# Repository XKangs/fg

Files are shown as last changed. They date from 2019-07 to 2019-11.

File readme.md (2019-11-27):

#block dirgram
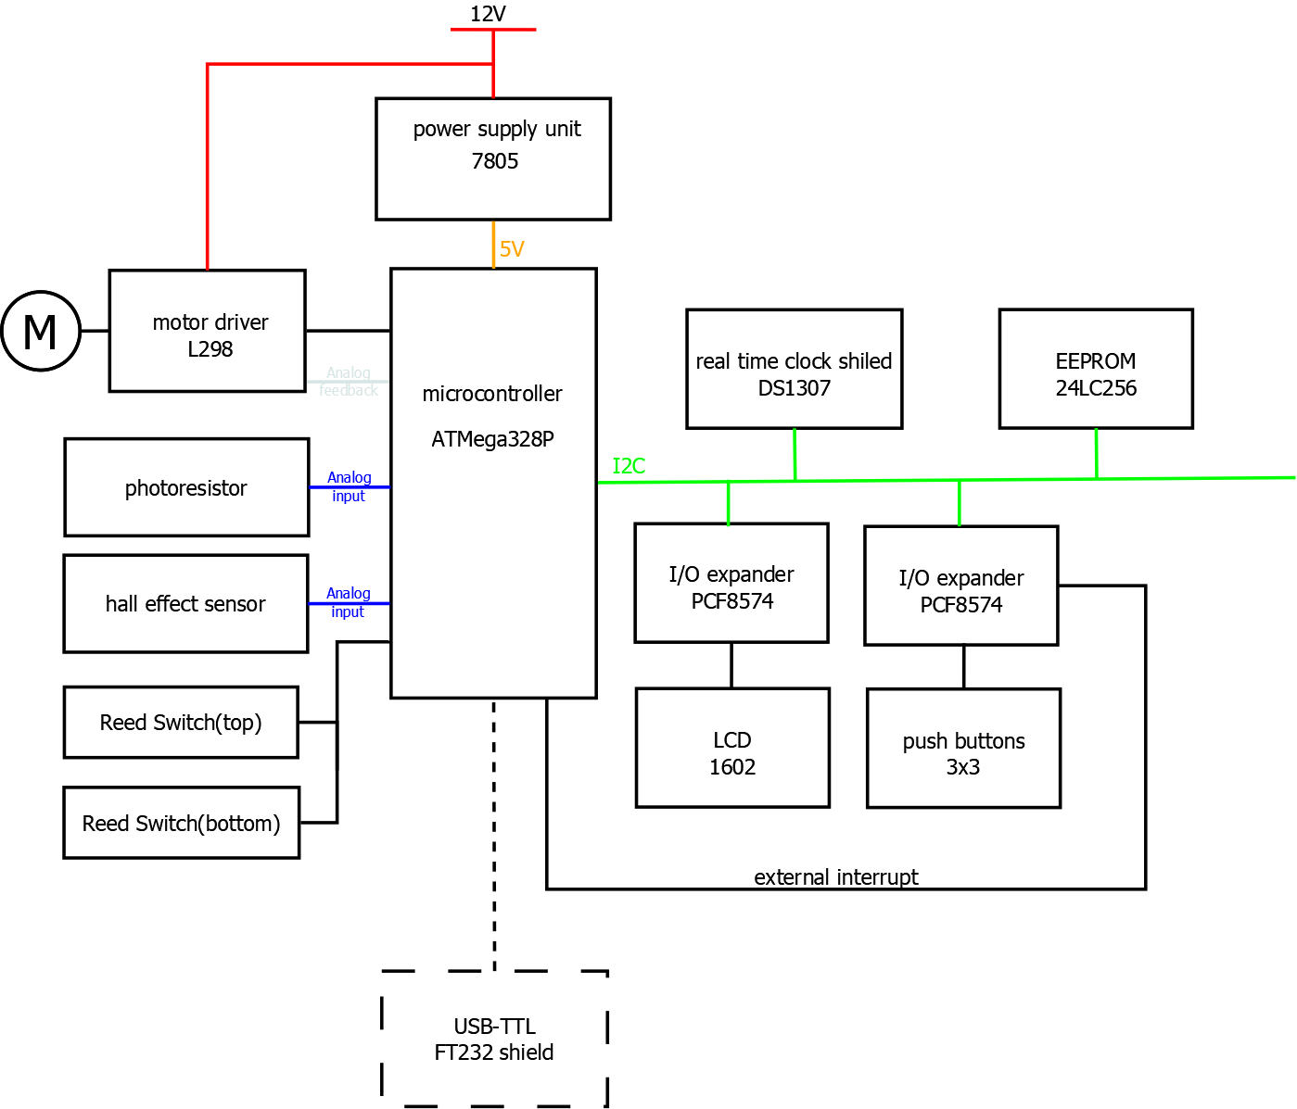
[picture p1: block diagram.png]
block diagram


---
this branch is for writting my report, it has its own schematic and PCB layout but doesn't have the code because it haven't been manufactured and built. 

hopefully somebody can finish it one day, I have spent soooooo much time on it...

---
xKang 
27 November 2019

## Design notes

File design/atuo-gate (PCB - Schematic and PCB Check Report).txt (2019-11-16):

Schematic and PCB Check Report
------------------------------

Report Written:     Saturday, November 16, 2019
Project Path:       C:\Users\xKang\Desktop\fg\design\atuo-gate.prj
Design Path:        C:\Users\xKang\Desktop\fg\design\atuo-gate.pcb
Design Title:       
Created:            27/07/2019 12:11:12 AM
Last Saved:         14/11/2019 2:04:38 PM
Editing Time:       1642 min
Units:              thou (precision 0)

Checking integrity of Schematic "C:\Users\xKang\Desktop\fg\design\atuo-gate.prj" with PCB "C:\Users\xKang\Desktop\fg\design\atuo-gate.pcb"
==========================================================================================================================================

End Of Report.

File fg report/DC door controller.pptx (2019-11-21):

## DC door controller

By Kevin

## Block diagram

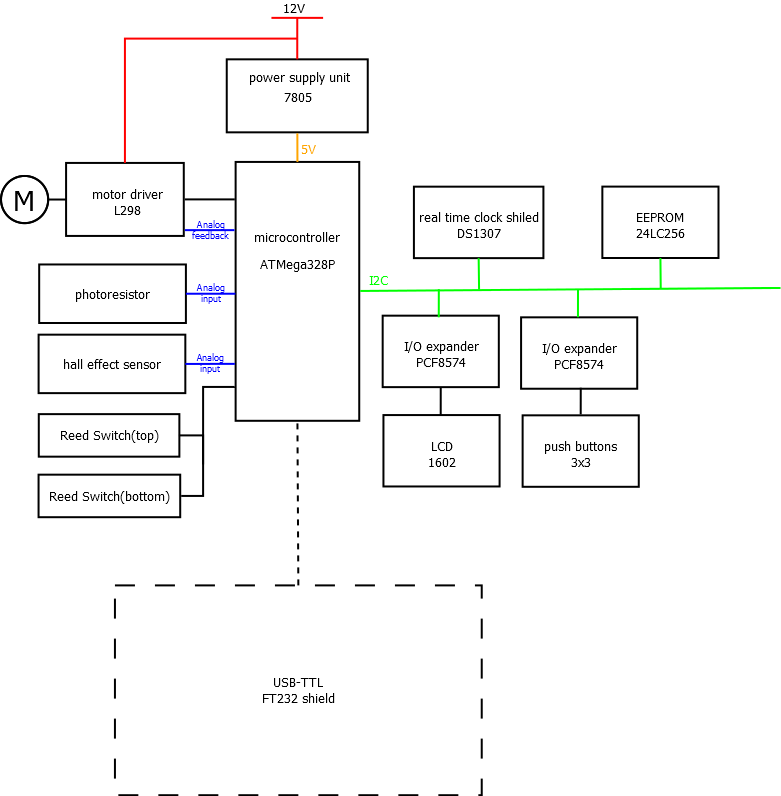
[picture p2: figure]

## components

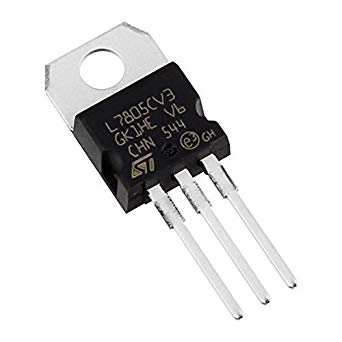
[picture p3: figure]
Image result for lm7805

PSU LM7805

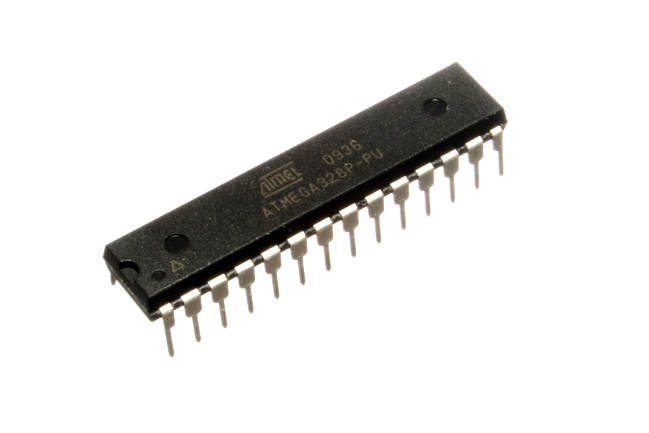
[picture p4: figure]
Image result for an At mega 328P

Microcontroller At mega 328P

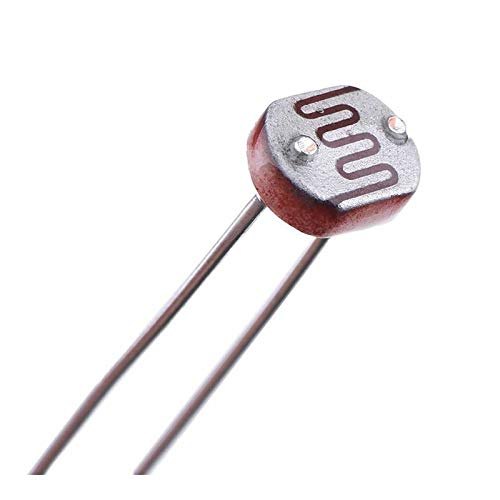
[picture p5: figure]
Image result for Photoresistor

Photoresistor

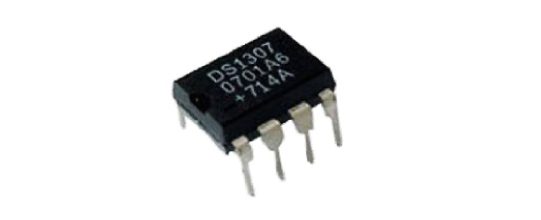
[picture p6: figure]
Image result for DS1307 ic

RTC DS1307

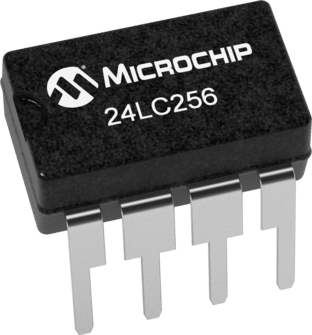
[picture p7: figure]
Image result for 24LC256

EEPROM 24LC256

## components

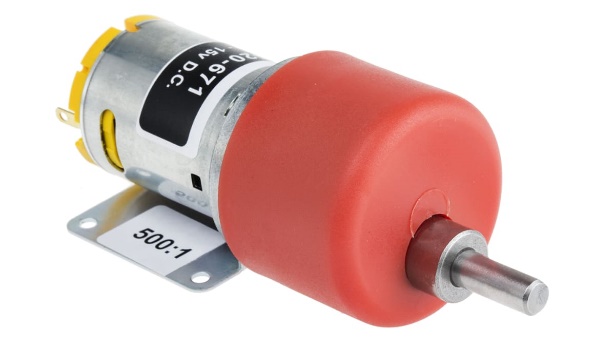
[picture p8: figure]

DC Motor with 500:1 gearbox

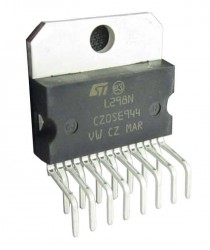
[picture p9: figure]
Image result for L298N

Motor drive
L298N

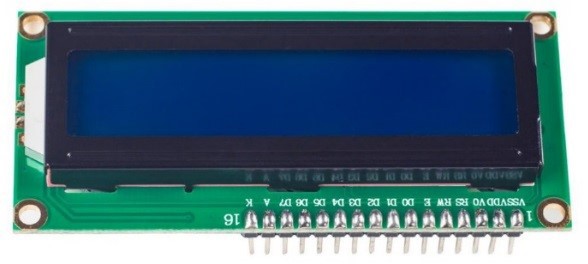
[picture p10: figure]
Image result for lcd 1602

1602 LCD

## PCB

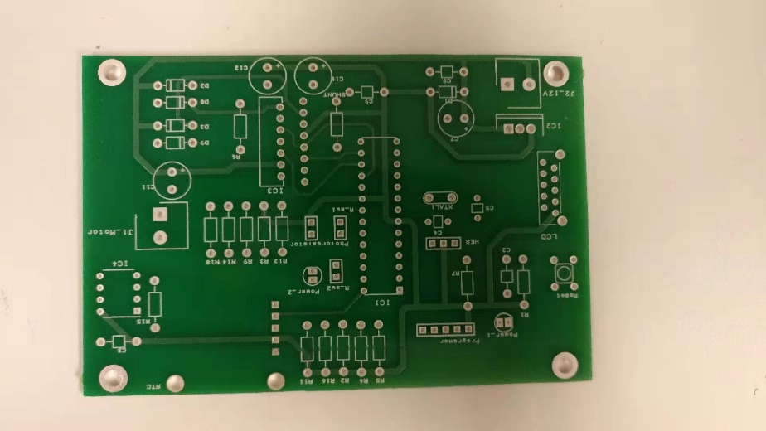
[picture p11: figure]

## interior

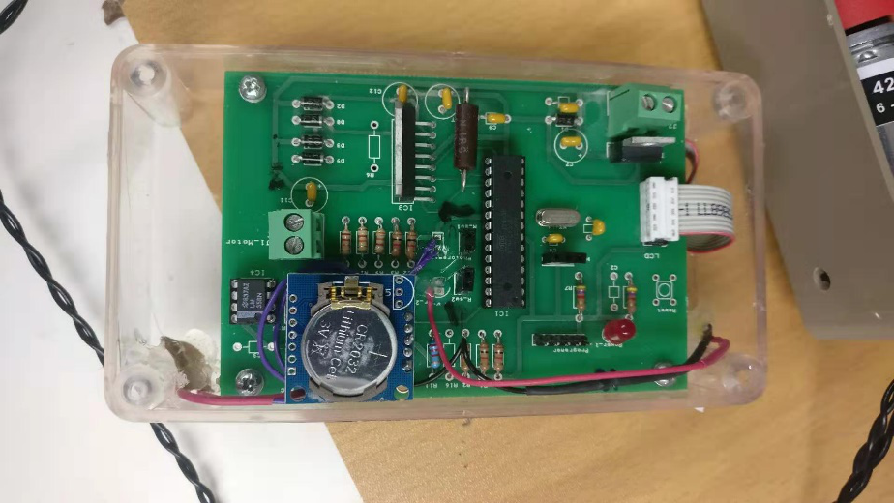
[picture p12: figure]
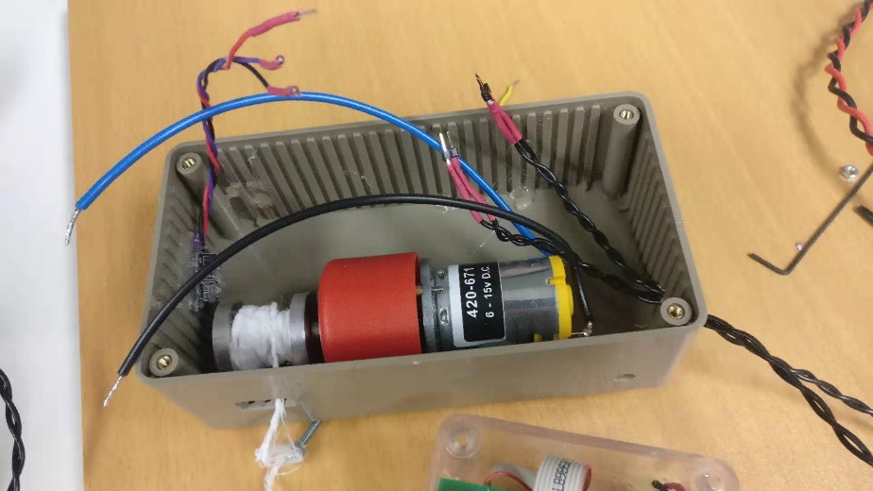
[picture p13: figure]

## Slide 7

Thank you

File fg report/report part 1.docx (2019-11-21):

DC motor door controller

By Kevin

## Block diagram


## Component describes

### Power supply unit

Image result for lm7805

The circuit is designed to be powered by 12V, but the micro controller and sensors are using 5V, so we need a Power supply unit to step down the voltage form 12V to 5V. I pick up a LM7805, this is one of the most popular voltage regulator, it is cheap and easy to configure.

### Microcontroller

Image result for an At mega 328P

Microcontroller is the brain of the circuit, all the input feed into the microcontroller, be processed and control the door open or close. I use an At mega 328P because it is the same chip as Arduino Uno so I has so many libraries can use, and it has duel inline package so it is easy to solder and fault find.

### Motor driver and motor

Image result for L298N

Because the motor is drive by big current, so it can not directly connect to microcontroller, that’s why we need a motor driver. L298N is one of the most wildly use motor driver IC for small motor, it has 2 channels and each channel can handle up to 2A current, more over it has Multiwatt15 package so it is easy to solder and fault find.

The Motor that I pick up is a DC motor with 500:1 gear box. It is slow but very high torque.

### Real time clock

Image result for DS1307 ic

The door can be set to open and close at certain time, so it needs a real time clock. DS 1307 is a low-power RTC base on I²C bus, it masks it externally easy to wires and use. And it will connect to a battery as a backup power supply to keeping the counter running while the main power supply is off.

### EEPROM

Image result for 24LC256

electrically erasable programmable read-only memory can be used to log the door operation and daylight-saving information. 24LC256 is a 256Kb EEPROM comes with the RTC shield.

### LCD

Image result for lcd 1602

The door controller would need thing to show people what is its status, an LCD is a good idea. 1602 is what I like, I have use it before and Arduino has library for it. What I don’t like is it have to using at least 6 I/O, so I use a PCF8574 I/O expander, it can expand 8 I/O via I²C bus, and most importantly, Arduino has library for that.

### Keypad

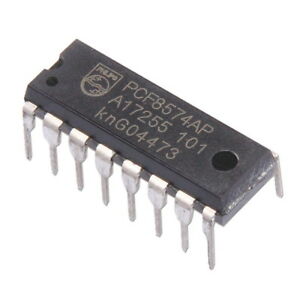
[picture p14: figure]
Image result for PCF8574 ic

The door controller would need thing to interact with human, that is why I put a keypad into my project. It can be used to manually operate the door and change setting in programming mode. That’s why I put a 3*3 keypad, because it can use to input number 1-9 and arrow key. Due to a 3*3 keypad would need at least 6 I/O, so I use a PCF8574 I/O expander.

### Photoresistor (LUX sensor)

Image result for Photoresistor

LUX sensor can be one of the sensors to determine when the door should open or close. A photoresistor is cheap, reliable and easy to use. It changes the resistance according to the light, I put it into a voltage divider and get the reading.

### Reed switch

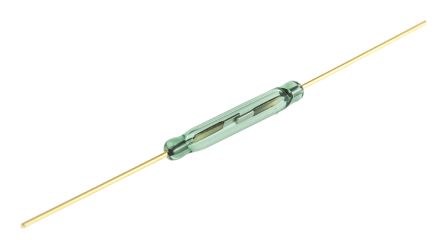
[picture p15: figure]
Image result for reed switch

Although a DC motor is cheap and easy to drive, we can accurately control the door’s position, that is why I put a reed switch on the top and bottom of the door. When the reed switch engages, the microcontroller will stop the motor.

### Hall effect sensor

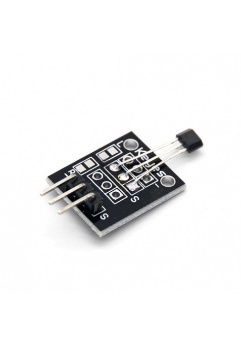
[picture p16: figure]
Image result for hall effect sensor

Although we have reed switch to detect the door’s position, it is better to have another sensor to be double safety factor also to detect the door is jammed or not. That is why I include a hall effect sensor in my project. We put a magnetic on the wheel, when the door is opening, the magnetic rotate and cut the magnetic field regularly, the hall effect sensor can receive this signal. When this signal lost, the microcontroller will know the door is jammed and taking action to stop the motor.

## Schematic

## Bill of Materials

## Print circuit board

## Current shunt

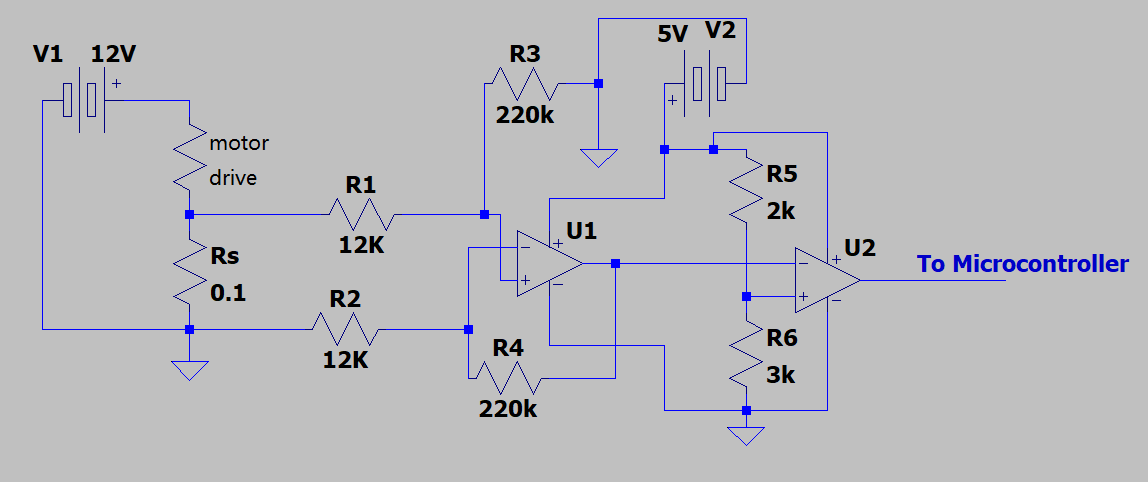
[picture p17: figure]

The current is a difference amplifier and a comparator. The shunt resister is series with the motor drive, so the voltage drop is direct proportion to the current. and according to the datasheet, the l298N can handle 2A of current.

### Difference amplifier

when R1=R2,R3=R4, V_(out) =(R3)/(R1)(V_(non-inverting) -V_(inverting) ) gain= (220K)/(12K)=18.3 V_(shunt) =IR=1.6×0.1=0.16V V_(out) =0.15V×18.3= 2.93V

### Comparator

That is a penitential divider on the non-inverting input of the op amp as a setting voltage, when the input voltage of the inverting input is lower than the setting voltage, it will output supply voltage(5V), but when it is higher than the setting voltage, it will pull to grand; it is acting as a extremal interrupt on the microcontroller, when the microcontroller receive this signal it will stop the motor rotating to prevent further damage.

setting voltage= V_(in) ×(R6)/(R5+R6)=3V

Therefor, when current is bigger than 1.6A, the motor will be stopped.

## Build and testing


Figure 1 PCB


Figure 2 interior


Figure 3 interior

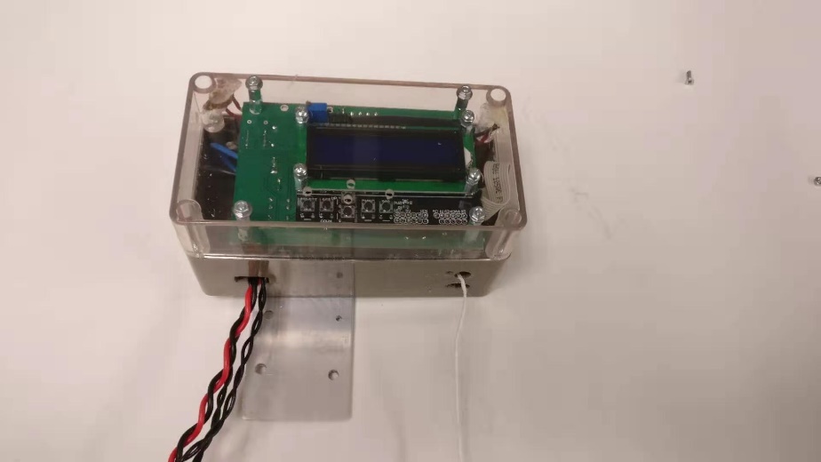
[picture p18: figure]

Figure 4 final product

## Code

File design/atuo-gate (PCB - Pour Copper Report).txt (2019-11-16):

Pour Copper Report
------------------

Report Written:     Saturday, November 16, 2019
Project Path:       C:\Users\xKang\Desktop\fg\design\atuo-gate.prj
Design Path:        C:\Users\xKang\Desktop\fg\design\atuo-gate.pcb
Design Title:       
Created:            27/07/2019 12:11:12 AM
Last Saved:         16/11/2019 4:32:07 PM
Editing Time:       1678 min
Units:              thou (precision 0)

End Of Report.

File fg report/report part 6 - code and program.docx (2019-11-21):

## Code & Program

### Program flow chart

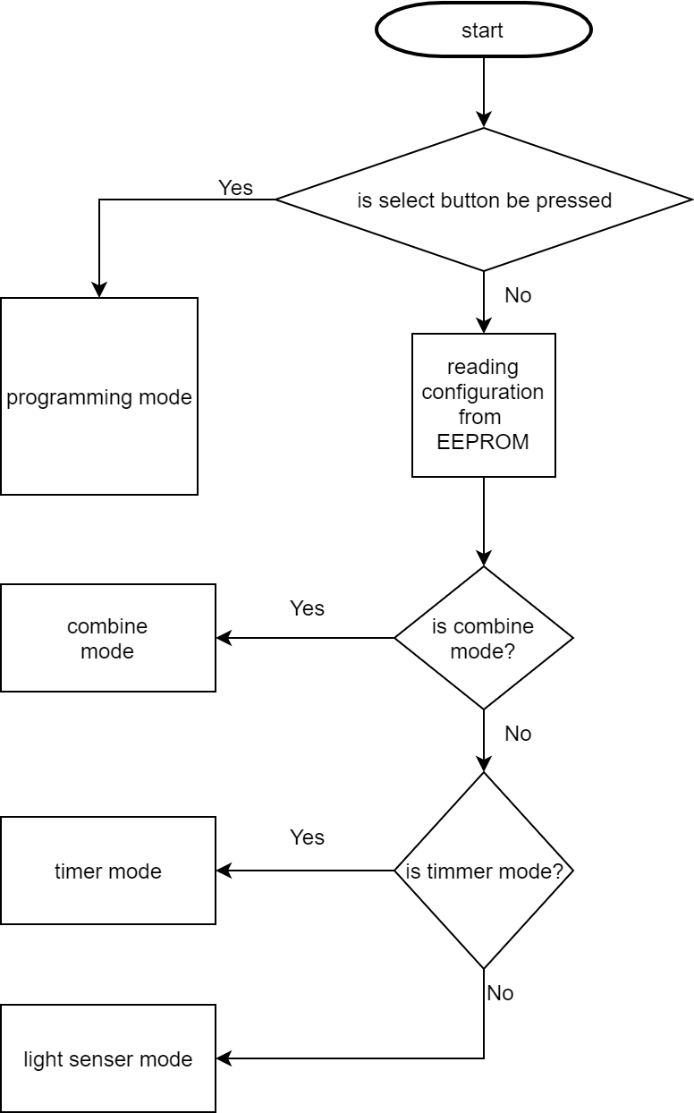
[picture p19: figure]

Figure 1 mode select

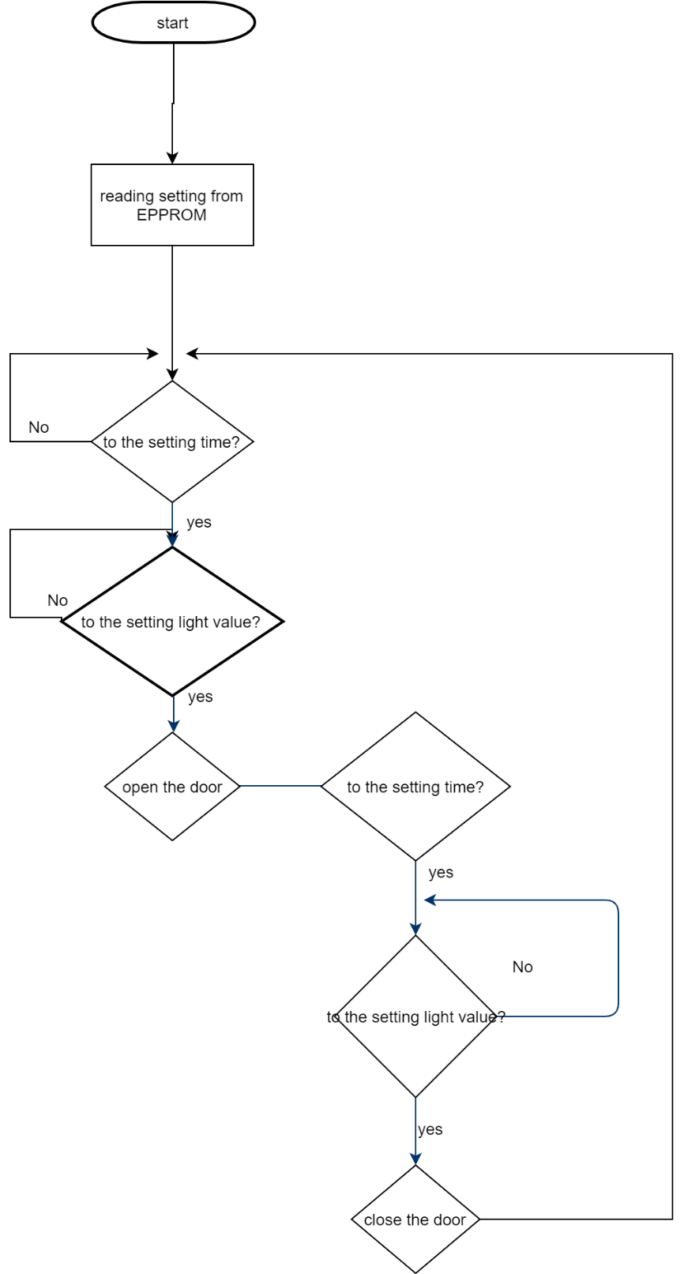
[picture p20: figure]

Figure 2 operating for combine mode

Same principle for timer mode and light sensor mode, but the timer mode does not check the light and the light sensor mode does not care the time.

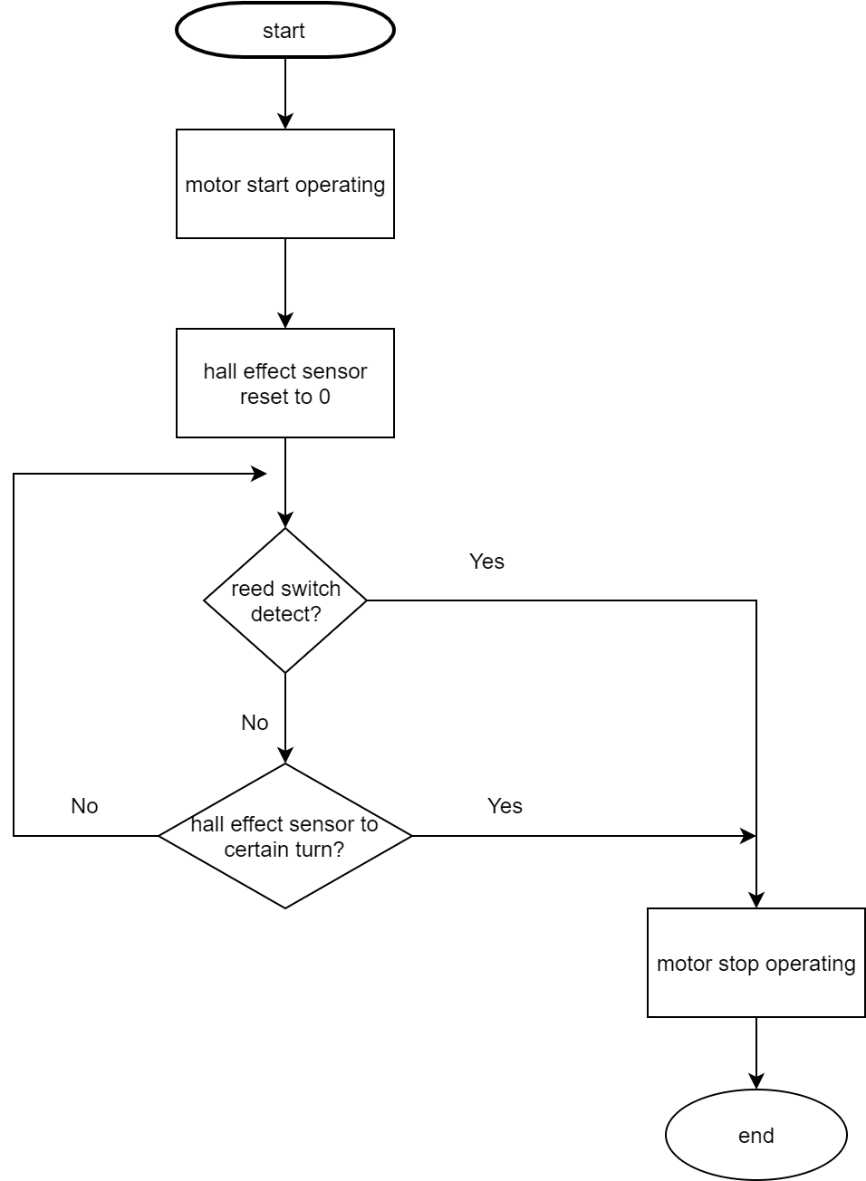
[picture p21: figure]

Figure 3 motor operation

### Code

/*

* * Project: DC door controller

** Author: xKang

** Date: 15/11/2019

*/

#include <LiquidCrystal.h>

#include <L298N.h>

#include <AnalogKeypad.h>

#include <Wire.h>

#include <TimeLib.h>

#include <Eeprom24C32_64.h>

#include <DS1307RTC.h>

#define INTERPUT_PIN 2 //over current interput

#define LDR_PIN A1

#define REED_TOP_PIN 13

#define REED_BOTTOM_PIN A3

#define HES_PIN 3

#define BUTTON_PIN A0

#define EEPROM_ADDRESS 0x50

static Eeprom24C32_64 _eeprom(EEPROM_ADDRESS);

AnalogKeypad _kp(A0);

//L298N _motor(EN, IN1, IN2);

L298N _motor(11, 12, 10);

//LiquidCrystal _lcd(rs, en, d4, d5, d6, d7);

LiquidCrystal _lcd(8, 9, 4, 5, 6, 7);

mode _mode = combine;

settingStore _conf;

tmElements_t tm;

int _turns = 0;

enum mode{

lightSensor,

timmer,

combine,

programming

};

static inline String modeToString(enum mode m)

{

String str[] = { "lightSensor", "timmer", "combine", "programming"};

return str[m];

}

class settingStore {

public:

settingStore();

mode _defaultMode = combine;

int _max_HES_turns;

int _lightOn;

int _lightOff;

int _timeOn;

int _timeOff;

void write(mode defaultMode, int max_HES_turns,int lightOn,int lightOff,int timeOn,int timeOff,int baseAddress = 0);

void read(int baseAddress = 0);

};

void setup() {

Serial.begin(9600);

_lcd.begin(16, 2);

if(_kp.getKey() == AnalogKeypad::select){

_mode = programming;

}else{

runningSetup();

}

}

void loop() {

switch(_mode){

case programming:{

programmingMode();

break;

}

case lightSensor:{

lightOpenFun();

openingFun();

lightCloseFun();

closingFun();

break;

}

case timmer:{

timeOpenFun();

openingFun();

timeCloseFun();

closingFun();

break;

}

case combine:

default:{

timeOpenFun();

lightOpenFun();

openingFun();

timeCloseFun();

lightCloseFun();

closingFun();

break;

}

}

}

/*

** other functions

*/

void setText(String text, int row,int col=0){

if (row == 0) {

_lcd.clear();

}

_lcd.setCursor(col, row);

_lcd.print(text);

}

/*

** statuses

*/

void timeOpenFun() {

setText("waiting timer", 0);

setText(("/"+String(_conf._timeOn)), 1, 14);

while (true) {

if (RTC.read(tm)) {

if (tm.Hour > _conf._timeOn) {

return;

}

}

if (_kp.getKey() == AnalogKeypad::up) {

return;

}

setText(String(tm.Hour,DEC),1);

delay(500);

}

}

void lightOpenFun() {

setText("waiting light", 0);

setText("/"+String(_conf._lightOn), 1, 16-4);

int luxReading;

while (true) {

luxReading = analogRead(LDR_PIN);

if (luxReading > _conf._lightOn){

return;

}

if (_kp.getKey() == AnalogKeypad::up) {

return;

}

setText(String(luxReading,DEC), 1);

delay(500);

}

}

void openingFun() {

setText("opening", 0);

setText("/"+String(_conf._max_HES_turns), 1, 16-3);

_turns = 0;

_motor.setSpeed(225);

_motor.forward();

while (digitalRead(REED_TOP_PIN) == HIGH && _turns < _conf._max_HES_turns) {

setText(String(_turns,DEC), 1);

delay(500);

}

_motor.fastStop();

delay(500);

_motor.disable();

}

void timeCloseFun() {

setText("waiting light", 0);

setText("/"+String(_conf._lightOff), 1, 16-4);

int luxReading;

while (true) {

luxReading = analogRead(LDR_PIN);

if (luxReading < _conf._lightOff){

return;

}

if (_kp.getKey() == AnalogKeypad::down) {

return;

}

setText(String(luxReading,DEC), 1);

delay(500);

}

}

void lightCloseFun() {

setText("waiting light", 0);

setText("/"+String(_conf._lightOff), 1, 16-4);

int luxReading;

while (true) {

luxReading = analogRead(LDR_PIN);

if (luxReading < _conf._lightOff){

return;

}

if (_kp.getKey() == AnalogKeypad::down) {

return;

}

setText(String(luxReading,DEC), 1);

delay(500);

}

}

void closingFun() {

setText("closing", 0);

setText("/"+String(_conf._max_HES_turns), 1, 16-3);

_turns = 0;

_motor.setSpeed(225);

_motor.backward();

while (digitalRead(REED_BOTTOM_PIN) == HIGH && _turns < _conf._max_HES_turns) {

setText(String(_turns,DEC), 1);

delay(500);

}

_motor.fastStop();

delay(500);

_motor.disable();

}

/*

* initialize function

*/

void runningSetup(){

pinMode(INTERPUT_PIN, INPUT);

//attachInterrupt(digitalPinToInterrupt(INTERPUT_PIN), overHeatAction, LOW);

pinMode(HES_PIN, INPUT);

attachInterrupt(digitalPinToInterrupt(HES_PIN), HESAction, RISING);

pinMode(LDR_PIN, INPUT);

pinMode(REED_TOP_PIN, INPUT);

pinMode(REED_BOTTOM_PIN, INPUT);

_conf.read();

}

void programmingMode(){

mode defaultMode = combine;

int max_HES_turns = 1,lightOn = 150,lightOff = 150,timeOn = 8, timeOff = 16;

setText("programming mode", 0);

setText("", 1);

delay(1000);

//section

setText("default mode", 0);

while(_kp.getKey() != AnalogKeypad::select){

setText(modeToString(defaultMode) + " mode ", 1);

if(_kp.getKey() == AnalogKeypad::up && defaultMode != 0){

defaultMode = defaultMode - 1;

}

if(_kp.getKey() == AnalogKeypad::down && defaultMode != 2){

defaultMode = defaultMode + 1;

}

delay(500);

}

while(_kp.getKey() == AnalogKeypad::select){}

//section

setText("door hight", 0);

while(_kp.getKey() != AnalogKeypad::select){

setText(String(max_HES_turns) + " ", 1);

if(_kp.getKey() == AnalogKeypad::up && max_HES_turns != 99){

max_HES_turns += 1;

}

if(_kp.getKey() == AnalogKeypad::down && max_HES_turns != 1){

max_HES_turns -= 1;

}

delay(500);

}

while(_kp.getKey() == AnalogKeypad::select){}

//section

setText("light to open", 0);

while(_kp.getKey() != AnalogKeypad::select){

setText(String(lightOn) + " ", 1);

if(_kp.getKey() == AnalogKeypad::up && lightOn != 1000){

lightOn += 25;

}

if(_kp.getKey() == AnalogKeypad::down && lightOn != 0){

lightOn -= 25;

}

delay(500);

}

while(_kp.getKey() == AnalogKeypad::select){}

//section

setText("light to close", 0);

while(_kp.getKey() != AnalogKeypad::select){

setText(String(lightOff) + " ", 1);

if(_kp.getKey() == AnalogKeypad::up && lightOff != 1000){

lightOff += 25;

}

if(_kp.getKey() == AnalogKeypad::down && lightOff != 0){

lightOff -= 25;

}

delay(500);

}

while(_kp.getKey() == AnalogKeypad::select){}

//section

setText("time to open", 0);

setText(" (24 hrs)", 1);

while(_kp.getKey() != AnalogKeypad::select){

setText(String(timeOn) + ":00 ", 1);

if(_kp.getKey() == AnalogKeypad::up && timeOn != 9){

timeOn += 1;

}

if(_kp.getKey() == AnalogKeypad::down && timeOn != 0){

timeOn -= 1;

}

delay(500);

}

while(_kp.getKey() == AnalogKeypad::select){}

//section

setText("time to close", 0);

setText(" (24 hrs)", 1);

while(_kp.getKey() != AnalogKeypad::select){

setText(String(timeOff) + ":00", 1);

if(_kp.getKey() == AnalogKeypad::up && timeOff != 23){

timeOff += 1;

}

if(_kp.getKey() == AnalogKeypad::down && timeOff != 13){

timeOff -= 1;

}

delay(500);

}

while(_kp.getKey() == AnalogKeypad::select){}

_conf.write(defaultMode,max_HES_turns,lightOn,lightOff,timeOn,timeOff,0);

setText("setting finish", 0);

setText("please reboot", 1);

while(true){delay(10000);}

}

/*

* for interput

*/

void overHeatAction() {

_motor.disable();

setText("over heat", 0);

setText("pls clear jam and reset", 1);

//waiting for reset

while(true){

delay(10000);

}

}

void HESAction(){

Serial.println("!!");

_turns++;

}

/*

* class settingStore

* I really should put it to another file

*/

settingStore::settingStore(){

_eeprom.initialize();

}

void settingStore::read(int baseAddress = 0){

int count = 6;

char buffer[count] = { 0 };

_eeprom.readBytes(baseAddress, count, buffer);

this->_defaultMode = (mode)buffer[0];

this->_max_HES_turns = buffer[1];

this->_lightOn = buffer[2] * 25;

this->_lightOff = buffer[3] * 25;

this->_timeOn = buffer[4];

this->_timeOff = buffer[5];

}

void settingStore::write(

mode defaultMode,

int max_HES_turns,

int lightOn,

int lightOff,

int timeOn,

int timeOff,

int baseAddress = 0

){

int count = 6;

char buffer[count] = { 0 };

buffer[0] = defaultMode;

buffer[1] = max_HES_turns;

buffer[2] = lightOn / 25;

buffer[3] = lightOff / 25;

buffer[4] = timeOn;

buffer[5] = timeOff;

_eeprom.writeBytes(baseAddress, count, buffer);

}

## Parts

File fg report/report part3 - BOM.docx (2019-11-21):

Component | Value | Package | Suppiler | Part Number | Qty | unit Price | total price | Ref Name | Description
ATMEGA328P-PU | | DIP28 | RS | 131-0275 | 1 | $5.06 | $5.06 | IC1 | MICROCHIP - ATMEGA328P-PU. - MICROCONTROLLER MCU, 8 BIT, ATMEGA, 20MHZ, DIP-28
battery cell | | 1053 | RS | 175-6055 | 1 | $3.45 | $3.45 | U1 | Coin Cell Battery Holders BATTERY HOLDER FOR CR2450
Capacitor | 100nF | DSC | jaycar | RG-5125 | 3 | $0.04 | $0.11 | C2, C8-9 | Capacitor
Capacitor | 22pf | DSC | element 14 | 169-4226 | 2 | $0.00 | $0.01 | C1, C6 | Capacitor
Capacritor_Pol | 0.1uF | DSCV | jaycar | RG-5125 | 1 | $0.38 | $0.38 | C4 | Capacitor
Capacritor_Pol | 0.33uF | DSCV | rs | 707-5650 | 1 | $0.04 | $0.04 | C3 | dc Aluminium Electrolytic Capacitor, Through Hole 5 (Dia.)
Capacritor_Pol | 100nF | DSCV | rs | 711-1396 | 2 | $0.04 | $0.09 | C5, C7 | dc Aluminium Electrolytic Capacitor, Through Hole 5 (Dia.)
Diode | 1N4001 | DSC | rs | 628-8931 | 9 | $0.31 | $2.77 | D1-9 | Diode
DS1307 | | DIP8 | rs | 540-2726 | 1 | $6.29 | $6.29 | RTC | Trickle charge timekeeping chip,DS1302 Maxim DS1302+ Real Time Clock, Alarm, Calendar, Clock, 31B RAM, Serial, 5.5 V, 8-Pin PDIP
hall effect sensor | | | jaycar | XC4434 | 1 | $6.20 | $6.20
HC49US-16.000MABJ-UB | | HC49 | digi key | 631-1108-ND | 1 | $0.35 | $0.35 | Y1 | Crystals 16MHz 18pF HC49S THROUGH HOLE
headers | | DSC | rs | 701-9953 | 3 | $1.29 | $3.86 | EN_KP, EN_LCD, EN_RTC,EN_CH2, reed_sw1-2,I2C, Programming,HES,ISP | 2 way male header, 2.54mm
IC | | TO3 | rs | 398-697 | 1 | $0.43 | $0.43 | IC4 | 3-Term Fixed 5V Volt Reg 4% TS7805CZ C0 TS7805CZ C0, Voltage Regulator, 2.2A 5 V, +/-4%, 3-Pin TO-220
IC | 24LC256-I_P | DIP8 | RS | 454-179 | 1 | $3.48 | $3.48 | EEPROM | Microchip 24LC256-I/P Serial EEPROM Memory, 256kbit, 900ns, 2.5 5.5 V 8-Pin PDIP
L298N | | MULTIWATT15V | rs | 636-384? | 1 | $10.43 | $10.43 | IC5 | L298N, Stepper Motor Controller, Dual Full Bridge Motor Driver, 4.8 46 V, 15-Pin MULTIWATT V
lcd keyped shield | | | jaycar | XC4454 | 1 | $22.40 | $22.40 | LCD
LED | LED 5MM GREEN | DSC | rs | 228-6004 | 1 | $0.04 | $0.04 | CLOSED | Light Em Di Green
LED | LED 5MM RED | DSC | rs | 228-5988 | 1 | $0.34 | $0.34 | POWER | Light Em Di RED
LM358N_NOPB | | DIP794W53P254L959H508Q8N | rs | 761-5860 | 1 | $1.38 | $1.38 | IC2 | Texas Instruments LM358N/NOPB, Dual Op Amp, 1MHz, 3 32 V, 8-Pin MDIP
motor | | | rs | 420-671 | 1 | $42.20 | $42.20
PCF8574N | | DIP254P762X508-16 | RS | 920-3393 | 2 | $2.02 | $4.04 | IC7, LCD_IO | REMOTE 8-BIT I/O EXPANDER FOR I2C BUS
Photoresistor | | DSC | rs | 466-1974 | 1 | $2.08 | $2.08 | Rp1
PMOS | | DSC | RS | 803-1093 | 1 | $0.13 | $0.13 | Q1 | MOSFET
Pushbutton | | DISC | rs | 119-1955 | 17 | $0.31 | $5.27 | RESET, SW11-14, SW21-24, SW31-34, SW41-44 | 6mm tactile buttons
read switch | | | rs | 361-4983 | 2 | $2.66 | $5.32
Resistor | 1K | DSC | element 14 | 1127904 | 6 | $0.03 | $0.18 | R3, R6, R8-10, R19 | Resistor
Resistor | 5K | DSC | element 14 | 1602150 | 1 | $0.39 | $0.39 | R1 | Resistor
Resistor | 0.2 | DSC | element 14 | 1684968 | 1 | $1.63 | $1.63 | Rshunt | shunt resistor
Resistor | 470 | DSC | rs | 707-7647 | 1 | $0.33 | $0.33 | R7 | Resistor
Resistor | 1.6K | DSC | rs | 739-7231 | 2 | $0.07 | $0.14 | R4-5 | Resistor
Resistor | 10K | DSC | rs | 707-7745 | 5 | $0.04 | $0.19 | R11-14, R16 | Resistor
Resistor | 12K | DSC | rs | 707-7757 | 2 | $0.04 | $0.07 | R2, R15 | Resistor
Resistor | 220K | DSC | rs | 707-8965 | 2 | $0.22 | $0.45 | R17-18 | Resistor
socket | | 16DIP | element 14 | 1103846 | 2 | $0.69 | $1.38
socket | | 28DIP | element 14 | 1103850 | 1 | $1.21 | $1.21
Resistor | 2K | DSC | | | 1 | $- | $- | R20 | Resistor
Resistor | 3K | DSC | | | 1 | $- | $- | R21 | Resistor
socket | | 8DIP | element 14 | 110-3844 | 2 | $0.34 | $0.67
Terminal blocks | | 20020316G021B01LF | element 14 | 171-1026 | 3 | $1.54 | $4.62 | 12Vin, M1-2 | Fixed Terminal Blocks 2P 5.00MM TERM BLK FIXED HORIZONTAL

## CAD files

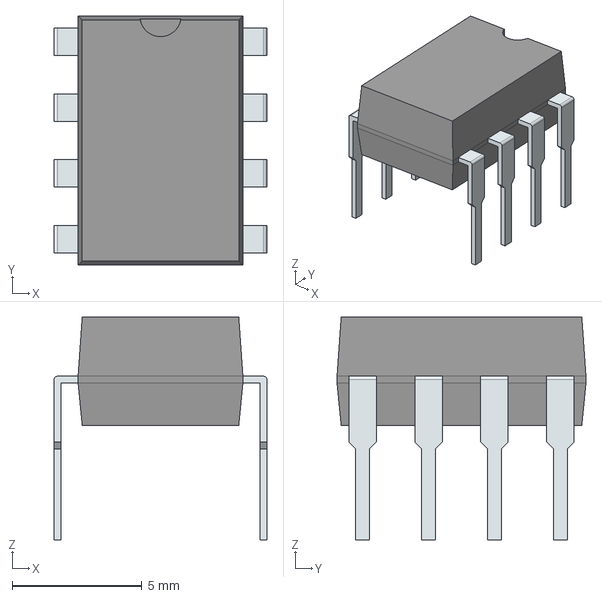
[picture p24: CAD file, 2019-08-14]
design/components/LM358N_NOPB.stp
8.21 x 9.59 x 8.58 mm
PinsArrayLR

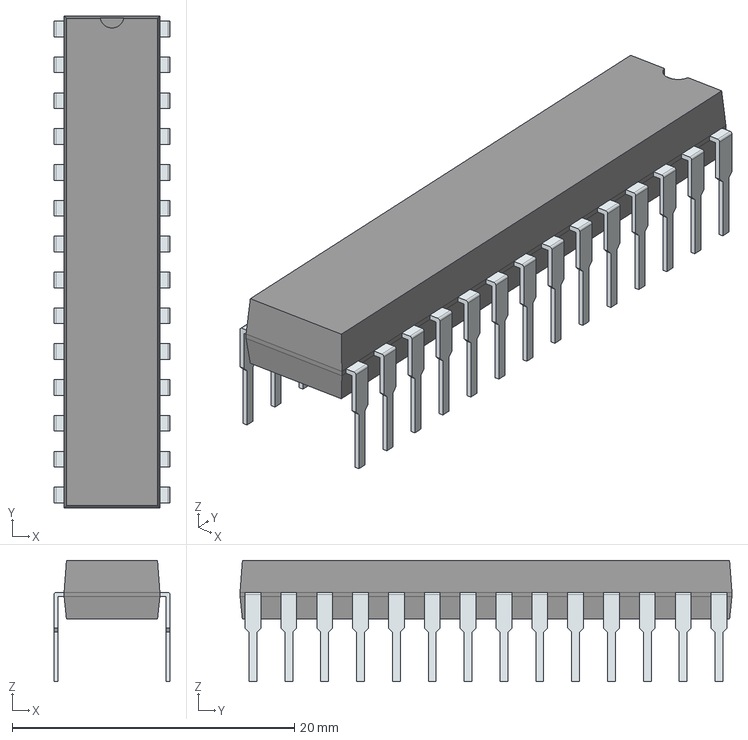
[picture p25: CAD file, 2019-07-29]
design/components/MCP23S17-E_SP.stp
8.22 x 34.9 x 8.58 mm
PinsArrayLR

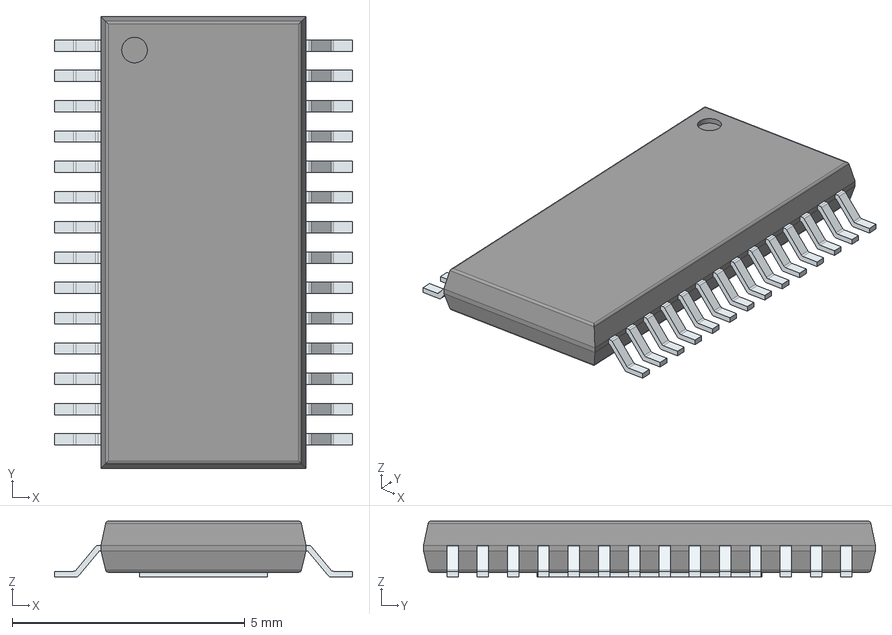
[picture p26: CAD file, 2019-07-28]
design/components/DRV8825PWPR.stp
6.40 x 9.70 x 1.20 mm
PinsArrayLR
ThermalPad

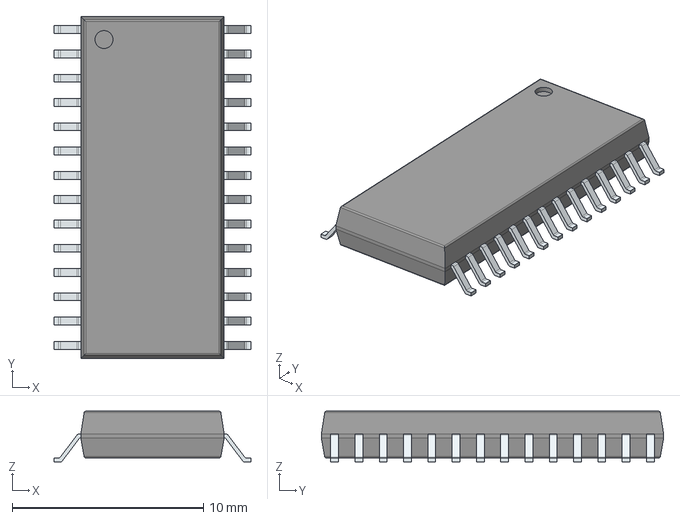
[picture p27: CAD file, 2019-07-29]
design/components/MCP23017T-E_SO.stp
10.3 x 17.9 x 2.65 mm
PinsArrayLR

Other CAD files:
design/components/MCP23017-E_SP.stp
design/components/DRV8825PWPR.stl
design/components/LM358N_NOPB.stl
design/components/MCP23017-E_SP.stl
design/components/MCP23017T-E_SO.stl
design/components/MCP23S17-E_SP.stl

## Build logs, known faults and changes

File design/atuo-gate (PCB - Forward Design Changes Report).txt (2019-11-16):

Forward Design Changes Report
-----------------------------

Report Written:     Saturday, November 16, 2019
Project Path:       C:\Users\xKang\Desktop\fg\design\atuo-gate.prj
Design Path:        C:\Users\xKang\Desktop\fg\design\atuo-gate.pcb
Design Title:       
Created:            27/07/2019 12:11:12 AM
Last Saved:         14/11/2019 2:04:38 PM
Editing Time:       1642 min
Units:              thou (precision 0)

Disconnected pin "IC5.15" from net "GND".

Changed value "Value" on component reference "R7" to "470".

Added net "N0099!MicroController!".
Added net "N0100!MicroController!".
Added net "MD_interrupt".
Added net "N0098!motor driver!".
Added net "N0103!motor driver!".
Added net "N0105!motor driver!".
Added net "N0112!motor driver!".
Added net "N0119!motor driver!".

Added component reference "R19" of component "Resistor", package "DSC".
Added component reference "CLOSED" of component "LED", package "DSC".
Changed value "Value" on component reference "CLOSED" to "LED 5MM GREEN".
Added component reference "Rshunt" of component "Resistor", package "DSC".
Changed value "Value" on component reference "Rshunt" to "0.2".
Added component reference "R2" of component "Resistor", package "DSC".
Changed value "Value" on component reference "R2" to "12K".
Added component reference "R15" of component "Resistor", package "DSC".
Changed value "Value" on component reference "R15" to "12K".
Added component reference "R17" of component "Resistor", package "DSC".
Changed value "Value" on component reference "R17" to "220K".
Added component reference "R18" of component "Resistor", package "DSC".
Changed value "Value" on component reference "R18" to "220K".
Added component reference "IC2" of component "LM358N_NOPB", package "DIP794W53P254L959H508Q8N".
Added component reference "R20" of component "Resistor", package "DSC".
Changed value "Value" on component reference "R20" to "2K".
Added component reference "R21" of component "Resistor", package "DSC".
Changed value "Value" on component reference "R21" to "3K".

Connected pin "IC1.5" to net "MD_interrupt".
Connected pin "IC1.11" to net "N0099!MicroController!".
Connected pin "R19.1" to net "GND".
Connected pin "R19.2" to net "N0100!MicroController!".
Connected pin "CLOSED.2" to net "N0099!MicroController!".
Connected pin "CLOSED.1" to net "N0100!MicroController!".
Connected pin "IC5.15" to net "N0098!motor driver!".
Connected pin "Rshunt.1" to net "GND".
Connected pin "Rshunt.2" to net "N0098!motor driver!".
Connected pin "R2.1" to net "N0098!motor driver!".
Connected pin "R2.2" to net "N0119!motor driver!".
Connected pin "R15.1" to net "GND".
Connected pin "R15.2" to net "N0103!motor driver!".
Connected pin "R17.1" to net "GND".
Connected pin "R17.2" to net "N0119!motor driver!".
Connected pin "R18.1" to net "N0105!motor driver!".
Connected pin "R18.2" to net "N0103!motor driver!".
Connected pin "IC2.1" to net "N0105!motor driver!".
Connected pin "IC2.2" to net "N0103!motor driver!".
Connected pin "IC2.3" to net "N0119!motor driver!".
Connected pin "IC2.4" to net "GND".
Connected pin "IC2.8" to net "+5V".
Connected pin "IC2.7" to net "MD_interrupt".
Connected pin "IC2.5" to net "N0112!motor driver!".
Connected pin "IC2.6" to net "N0105!motor driver!".
Connected pin "R20.1" to net "N0112!motor driver!".
Connected pin "R20.2" to net "+5V".
Connected pin "R21.1" to net "GND".
Connected pin "R21.2" to net "N0112!motor driver!".

End Of Report.

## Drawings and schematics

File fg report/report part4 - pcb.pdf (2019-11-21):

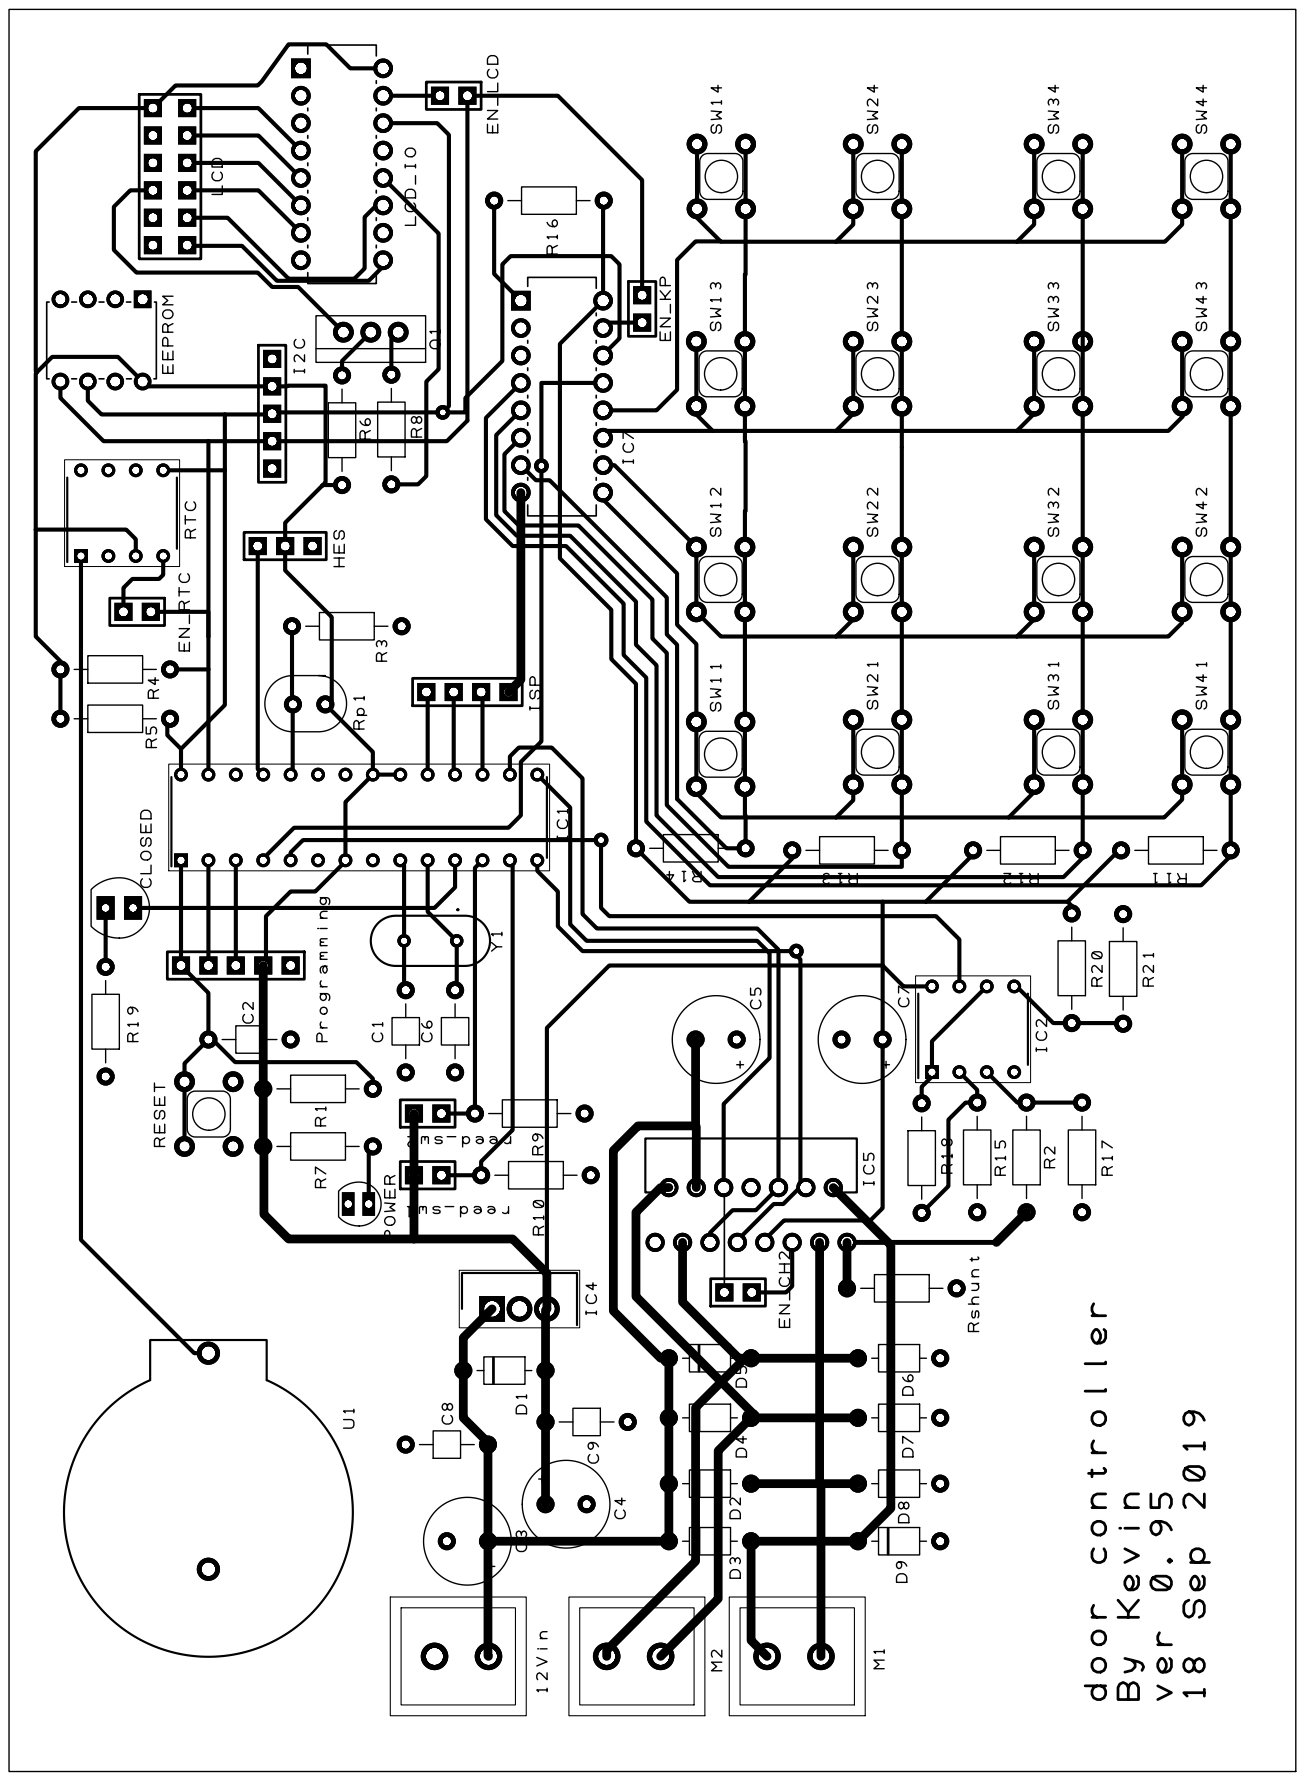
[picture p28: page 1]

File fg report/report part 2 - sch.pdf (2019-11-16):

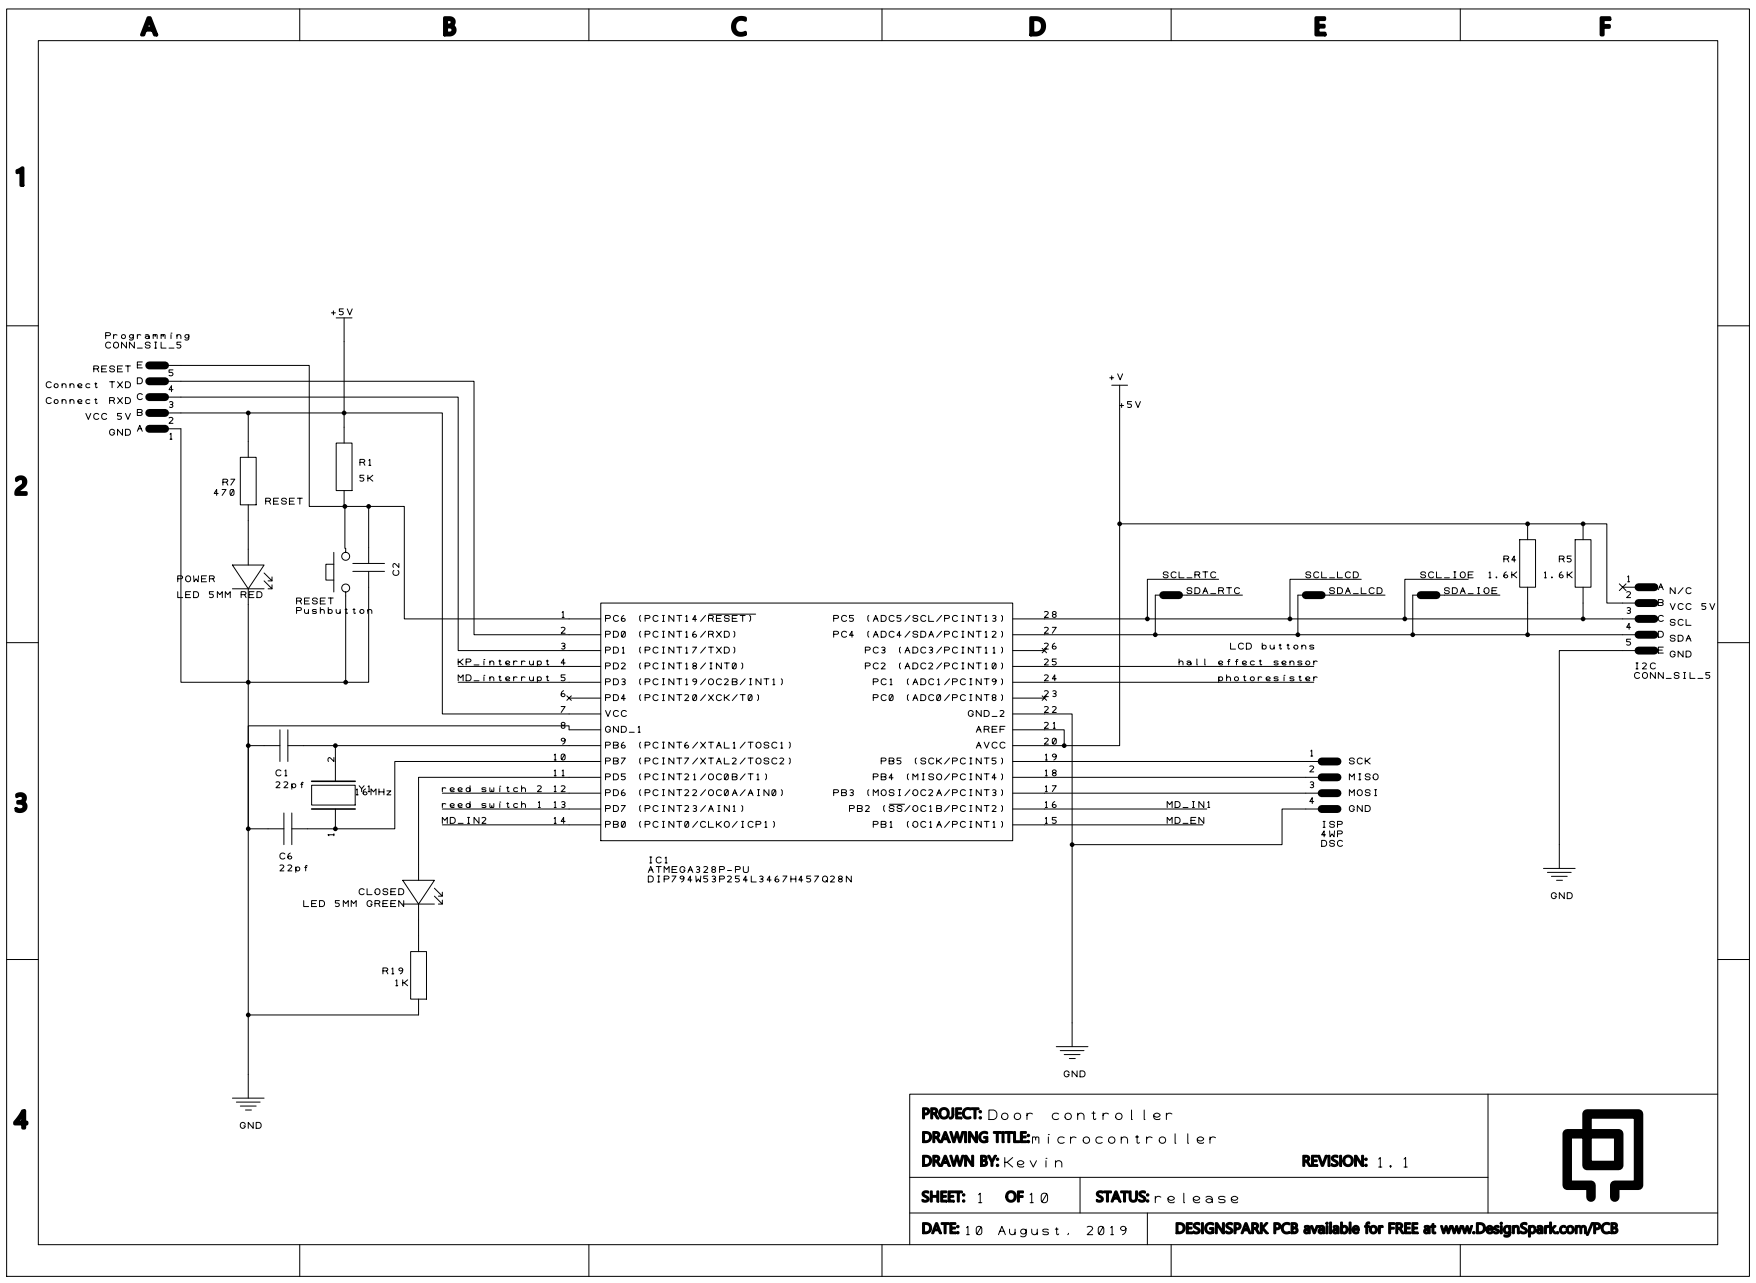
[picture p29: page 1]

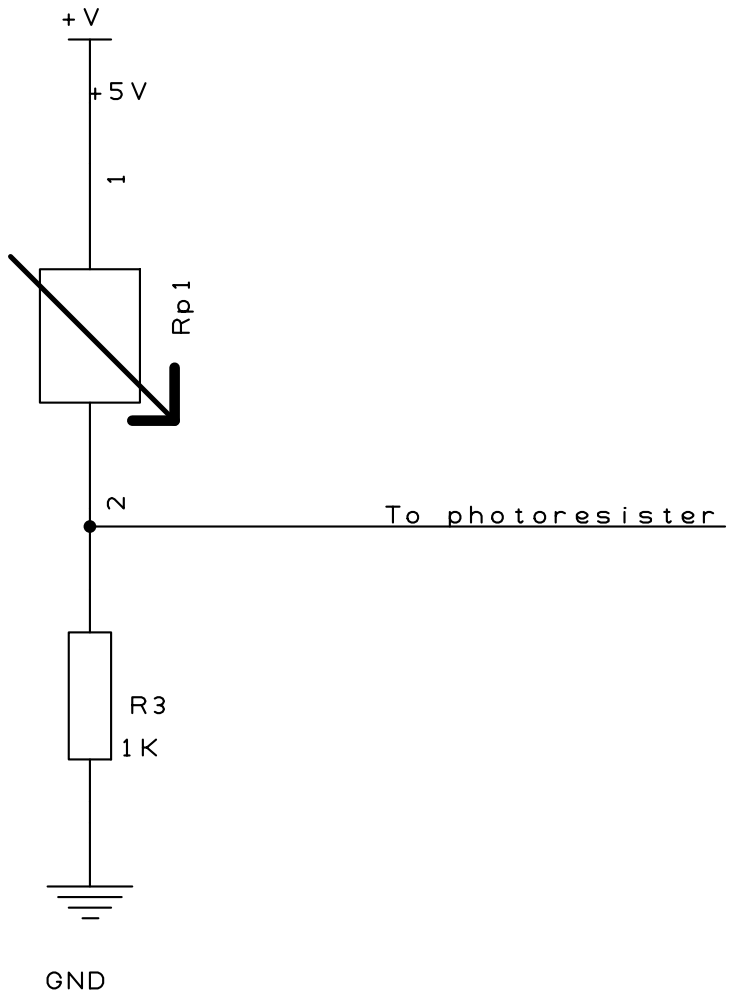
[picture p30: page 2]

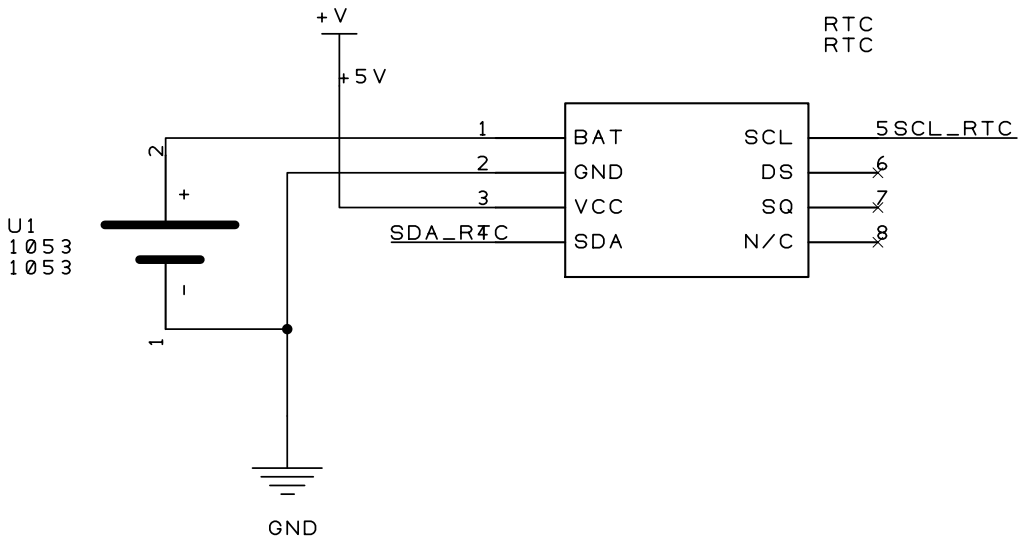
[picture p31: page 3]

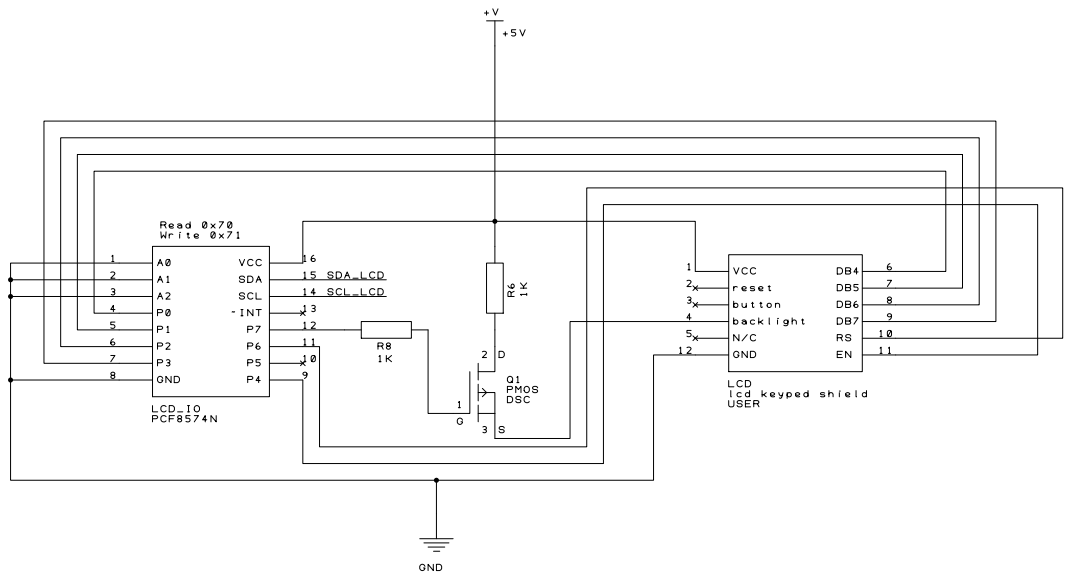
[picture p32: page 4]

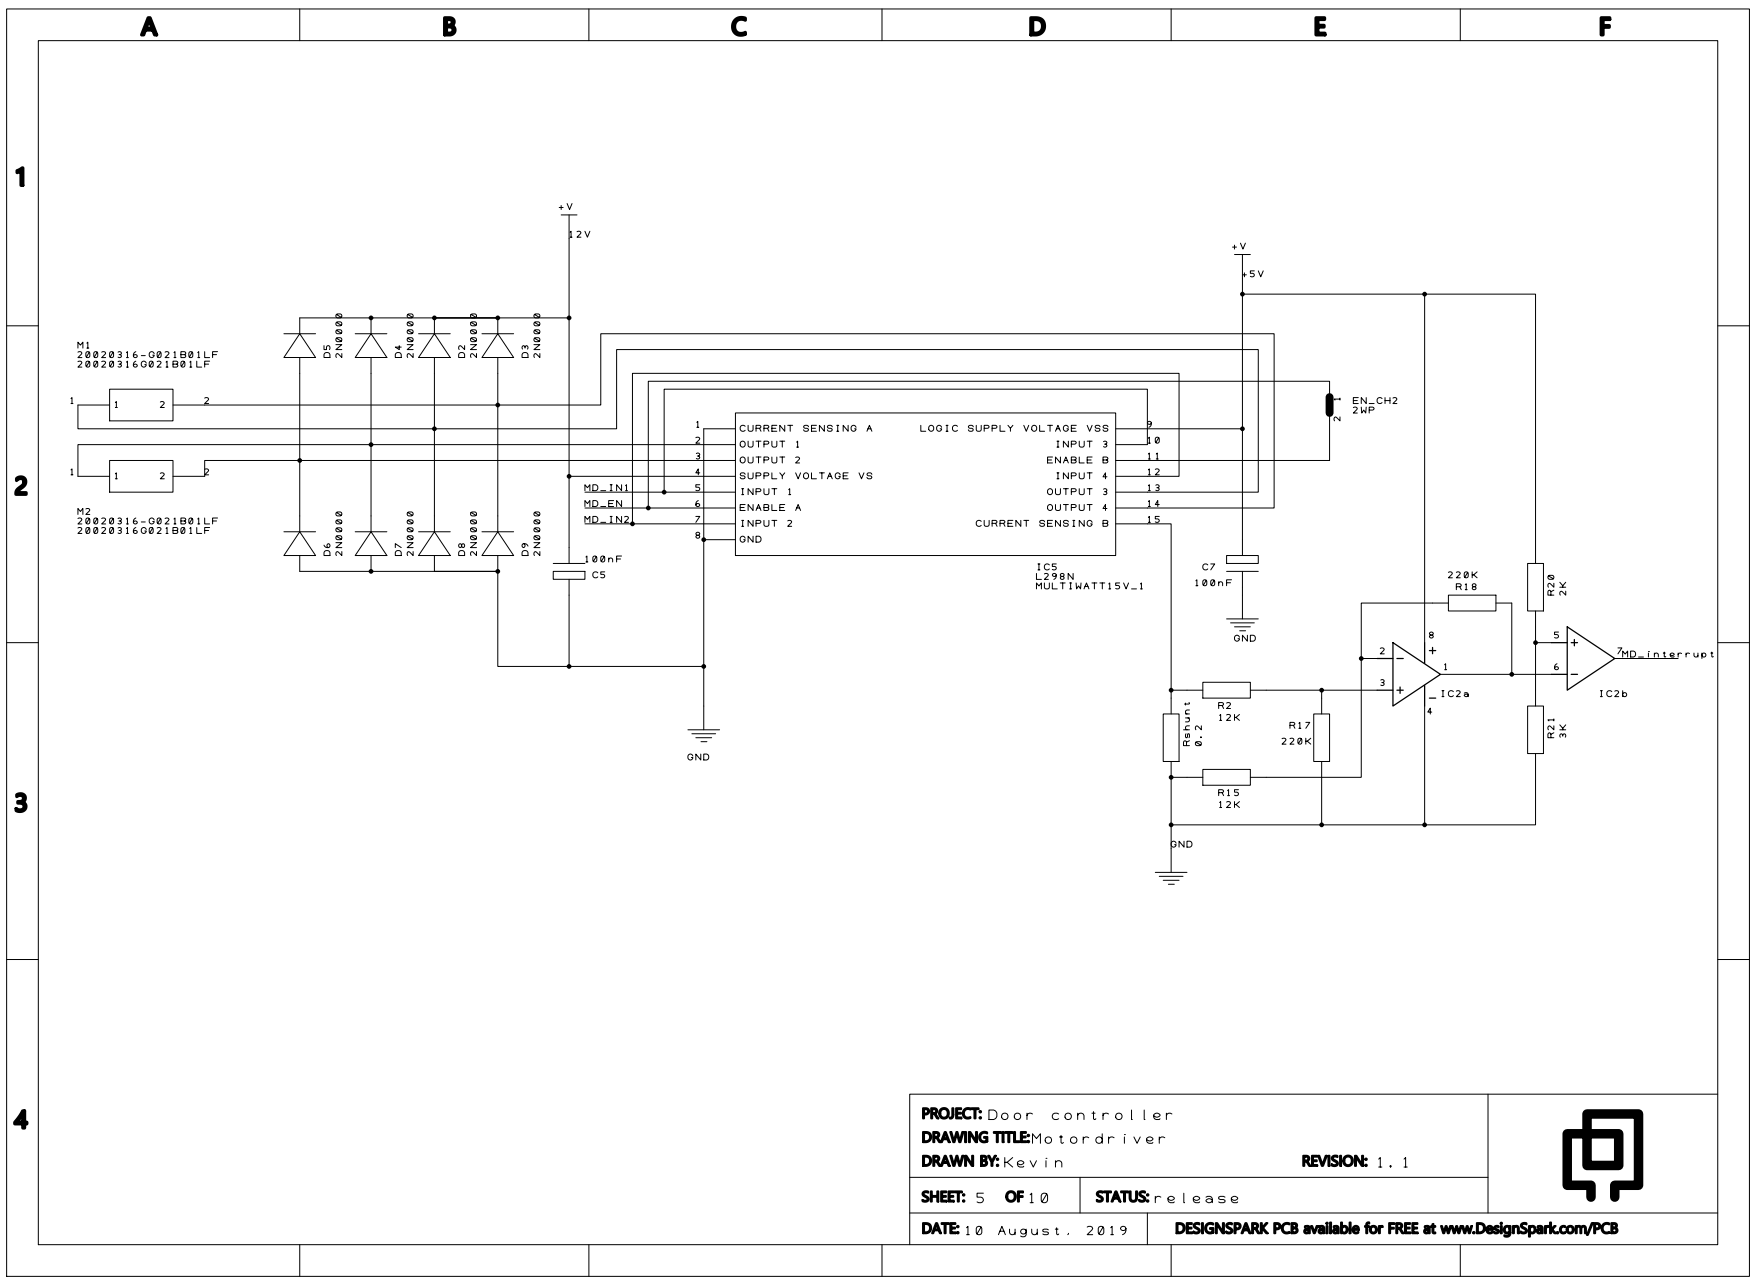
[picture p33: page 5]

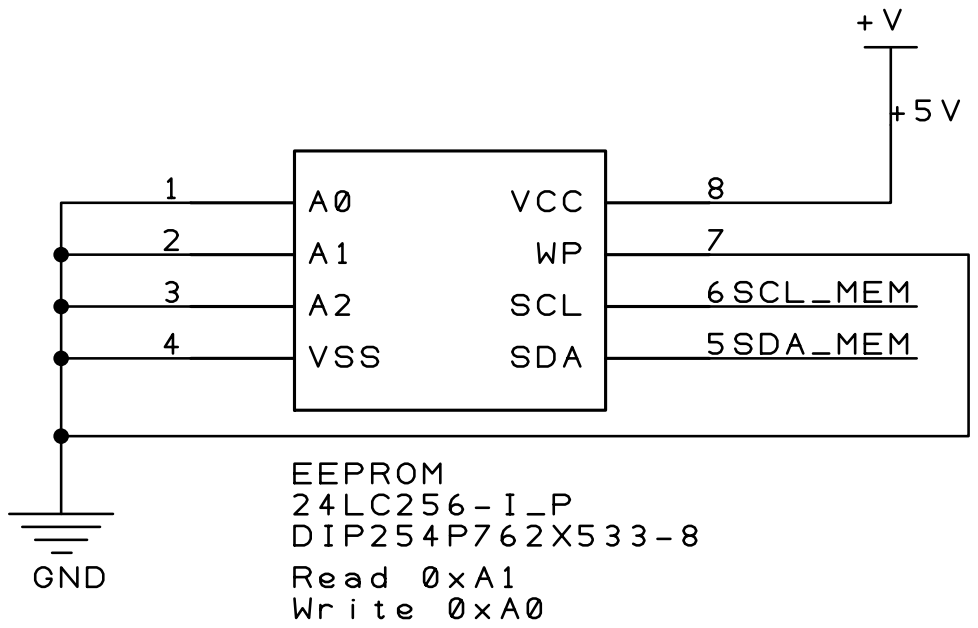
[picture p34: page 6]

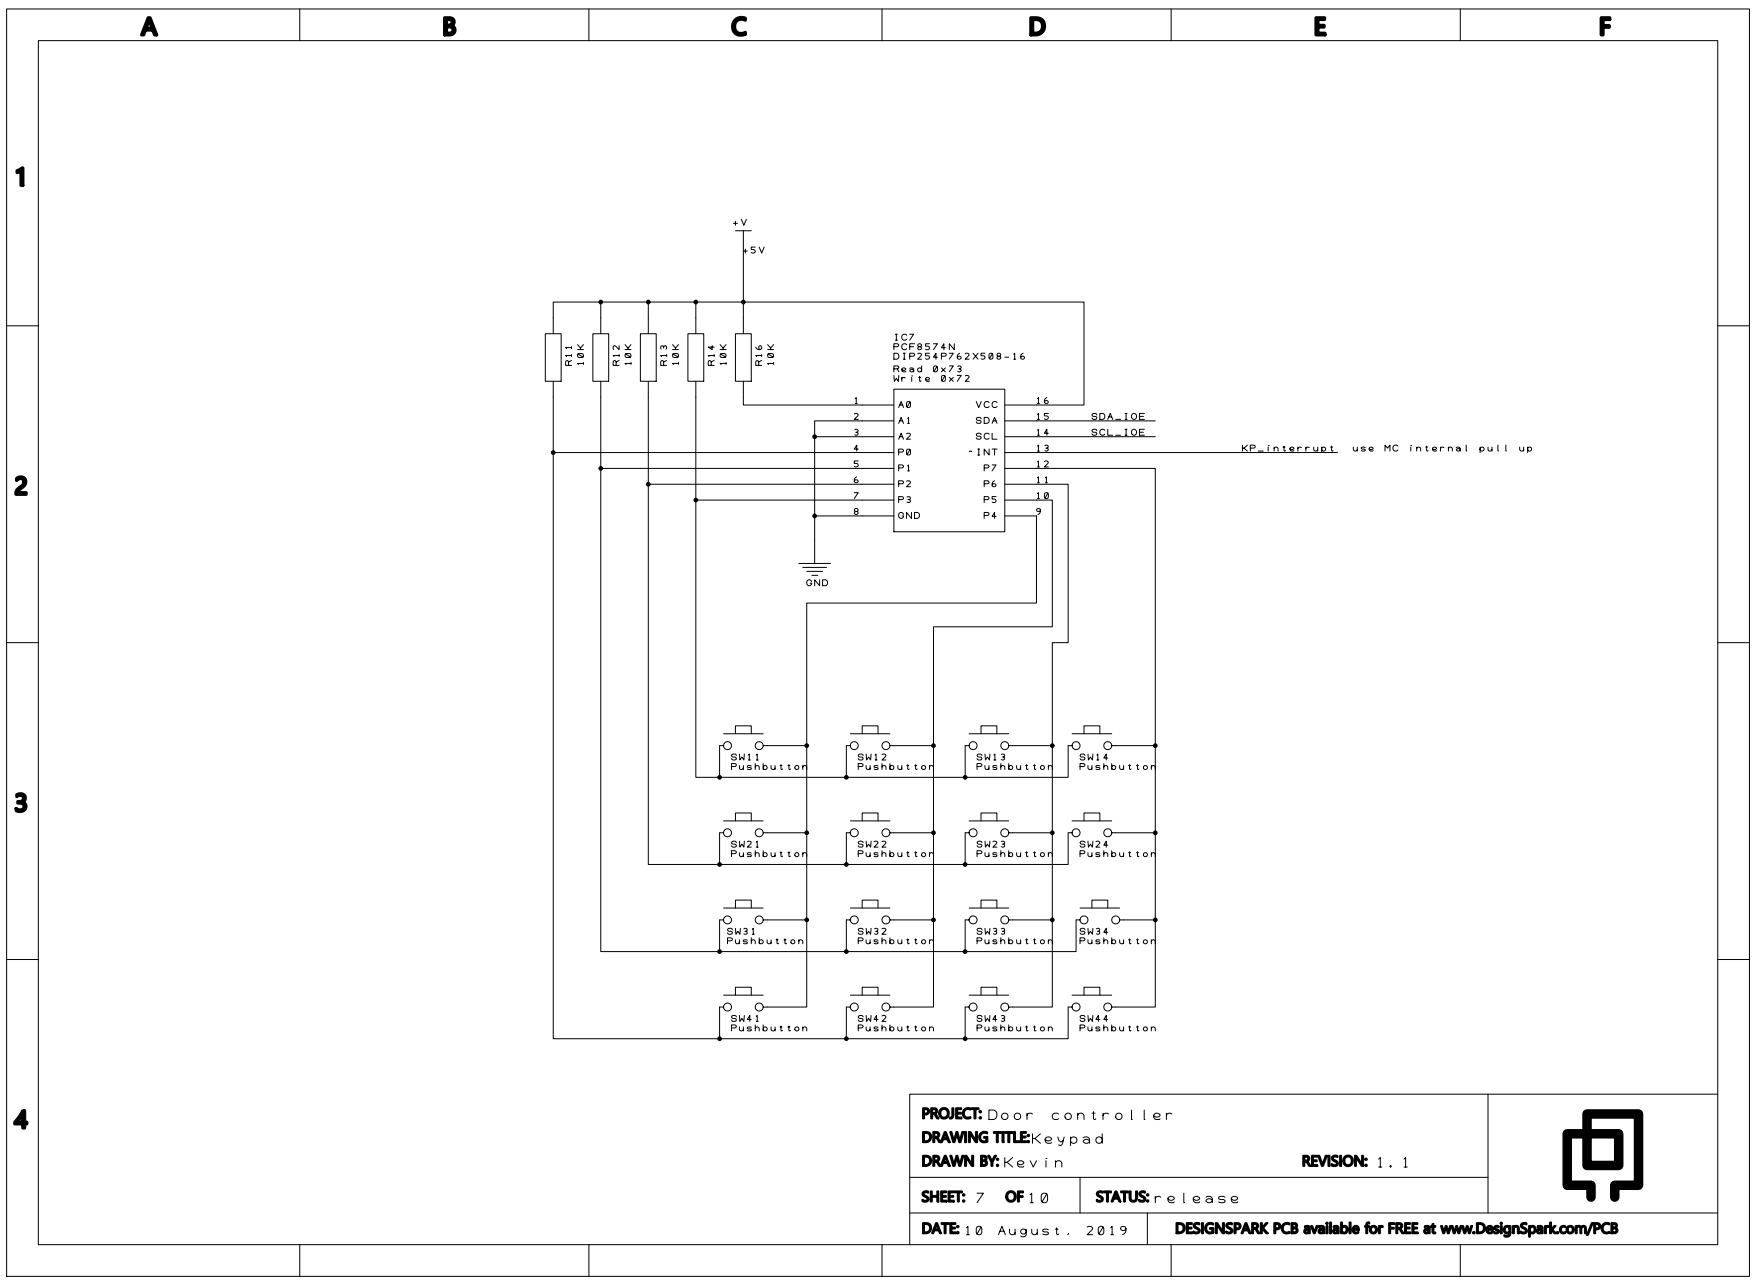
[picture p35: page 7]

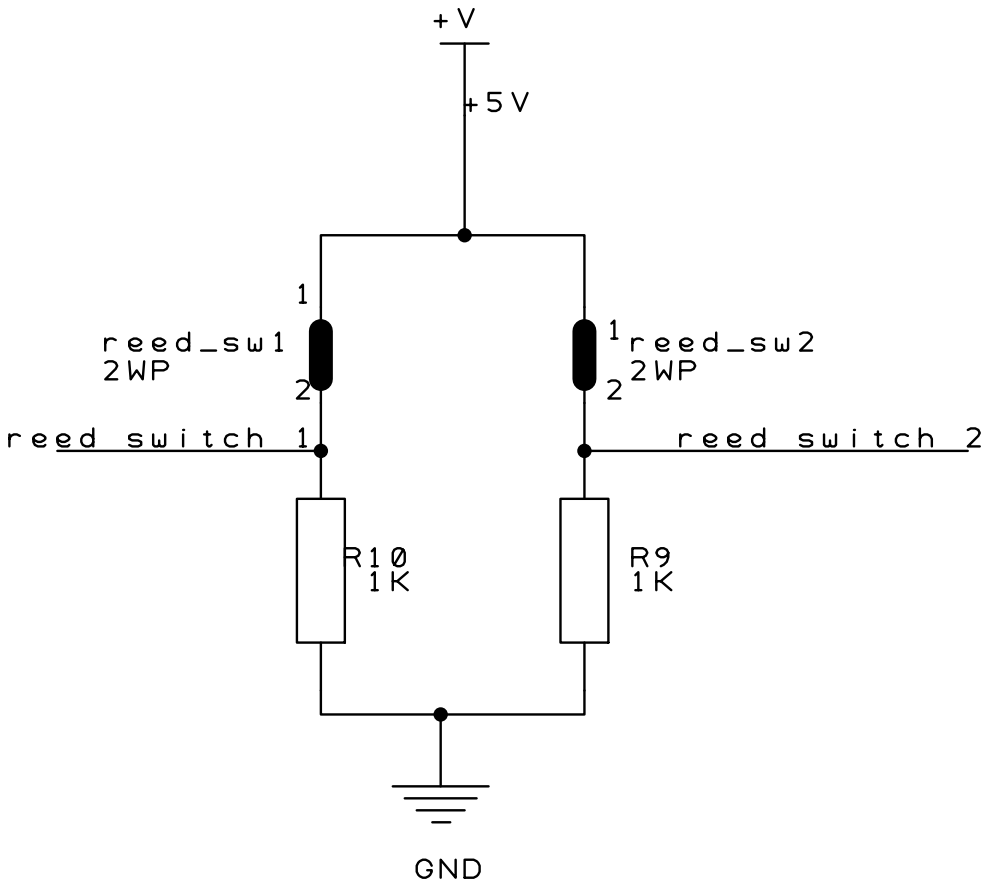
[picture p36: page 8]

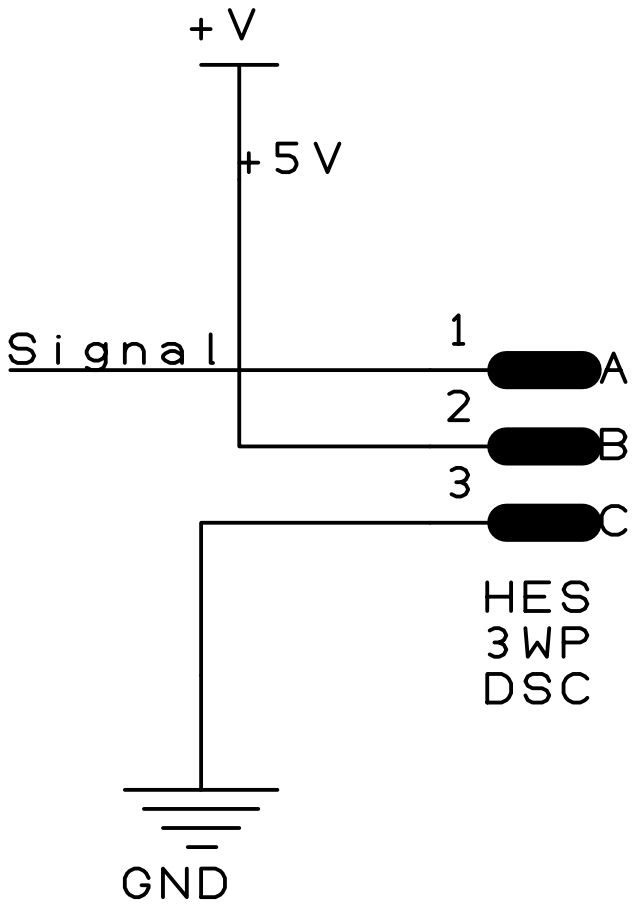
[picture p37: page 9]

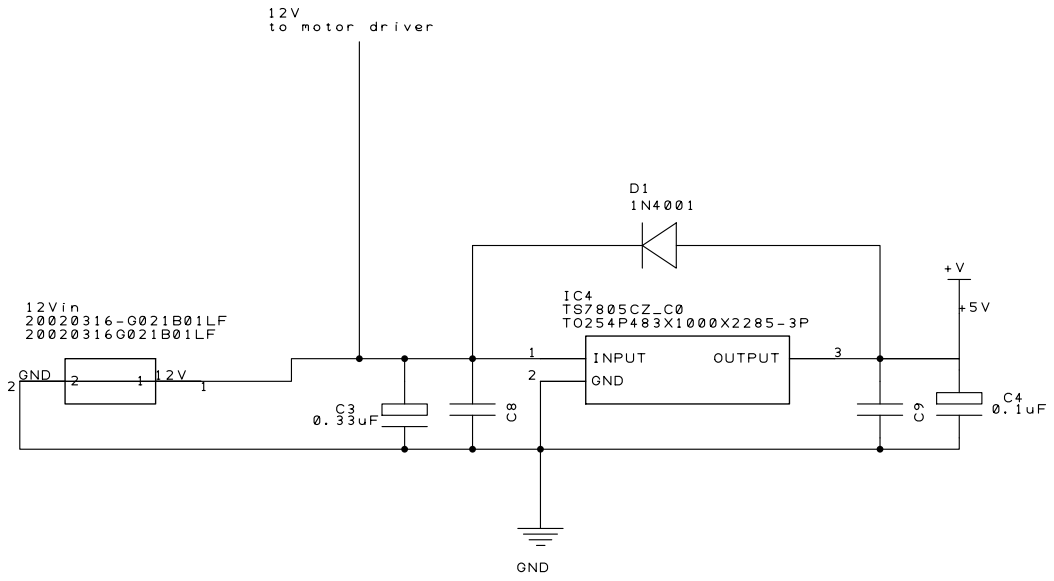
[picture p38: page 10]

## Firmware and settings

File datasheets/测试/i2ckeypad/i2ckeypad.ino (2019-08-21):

/*
 *  i2ckeypad.pde - keypad/I2C expander interface example for Arduino
 *
 *  Copyright (c) 2009 Angel Sancho <angelitodeb@gmail.com>
 *  All rights reserved.
 *
 *
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
 *
 *  EXPLANATION
 *  -----------
 *  This example was tested with PCF8574P and SPARKFUN 4x3 keypad wired
 *  as you can see in the image i2ckeypad_example_schema.png, and with
 *  default pin mapping of i2ckeypad library
 *
 *  R1, R2 and R3 are 10K
 */

#include <Wire.h>
#include <i2ckeypad.h>

int interruptPin = 2;
i2ckeypad kpd = i2ckeypad(0x20, 4, 4);

void setup()
{
  Serial.begin(9600);

  Wire.begin();

  kpd.init();
  
  pinMode(interruptPin, INPUT);
  attachInterrupt(digitalPinToInterrupt(interruptPin), inter, FALLING);
  
  Serial.println("Testing keypad");
}

void loop()
{
  /*
  char key = kpd.get_key();
  
  if(key != '\0') {
    Serial.print("from loop: ");
    Serial.println(key);  
  }  
  */
}

void inter(){
  Serial.println("inter"); 
  char key = kpd.get_key();
  
  //if(key != '\0') 
  {
      Serial.println(key);  
  }
}

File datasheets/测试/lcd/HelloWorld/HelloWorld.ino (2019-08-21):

/*
  LiquidCrystal Library - Hello World

 Demonstrates the use a 16x2 LCD display.  The LiquidCrystal
 library works with all LCD displays that are compatible with the
 Hitachi HD44780 driver. There are many of them out there, and you
 can usually tell them by the 16-pin interface.

 This sketch prints "Hello World!" to the LCD
 and shows the time.

  The circuit:
 * LCD RS pin to digital pin 12
 * LCD Enable pin to digital pin 11
 * LCD D4 pin to digital pin 5
 * LCD D5 pin to digital pin 4
 * LCD D6 pin to digital pin 3
 * LCD D7 pin to digital pin 2
 * LCD R/W pin to ground
 * LCD VSS pin to ground
 * LCD VCC pin to 5V
 * 10K resistor:
 * ends to +5V and ground
 * wiper to LCD VO pin (pin 3)

 Library originally added 18 Apr 2008
 by David A. Mellis
 library modified 5 Jul 2009
 by Limor Fried (http://www.ladyada.net)
 example added 9 Jul 2009
 by Tom Igoe
 modified 22 Nov 2010
 by Tom Igoe
 modified 7 Nov 2016
 by Arturo Guadalupi

 This example code is in the public domain.

 http://www.arduino.cc/en/Tutorial/LiquidCrystalHelloWorld

*/

// include the library code:
#include <LiquidCrystal.h>

// initialize the library by associating any needed LCD interface pin
// with the arduino pin number it is connected to
int analogPin = A0;
int interruptPin = 2;

const int rs = 8, en = 9, d4 = 4, d5 = 5, d6 = 6, d7 = 7;
LiquidCrystal lcd(rs, en, d4, d5, d6, d7);
bool backlight = true;

void setup() {
  // set up the LCD's number of columns and rows:
  lcd.begin(16, 2);
  // Print a message to the LCD.
  lcd.print("By Kevin");
  pinMode(10, OUTPUT);
  digitalWrite(10, backlight);

  pinMode(interruptPin, INPUT_PULLUP);
  attachInterrupt(digitalPinToInterrupt(interruptPin), inter, FALLING);
}
void loop() {
}


void inter() {  
  lcd.setCursor(0, 1);
  int val = analogRead(analogPin);  // read the input pin
  if(val > 1000){
    lcd.print("null  ");
  }else if(val > 600){
    lcd.print("select");
    while(analogRead(analogPin) < 1000){
      delay(50);
    }
    backlight = !backlight;
    digitalWrite(10, backlight);

  }else if(val > 400){
    lcd.print("left  ");
  }else if(val > 250){
    lcd.print("down  ");
  }else if(val > 90){
    lcd.print("up    ");
  }else{
    lcd.print("right ");
  }
  
}

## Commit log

2019-07-28 2019年7月28日14:12:53
2019-07-28 2019年7月28日19:41:50
    [LCD.sch, MicroController.sch, PSU.sch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]
2019-07-28 2019年7月28日21:13:10
    [DRV8825PWPR.stl, DRV8825PWPR.stp, MicroController.sch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]
2019-07-29 2019年7月29日17:49:55
    [LCD.sch, MicroController.sch, PSU.sch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]
2019-07-29 2019年7月30日00:21:12
    [IO extender.sch, MCP23017-E_SP.stl, MCP23017-E_SP.stp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]
2019-07-29 2019年7月29日2019年7月30日01:13:37
    [MicroController.sch]
2019-07-30 2019年7月30日15:43:14
    [IO expander.sch, LCD.sch, Memory.sch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]
2019-07-30 2019年7月30日23:53:13
    [IO expander.sch, LCD.sch, Memory.sch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]
2019-07-30 2019年7月31日00:27:34
    [IO expander.sch, MicroController.sch]
2019-07-31 2019年7月31日13:16:15
    [MicroController.sch, ~MicroController.sch]
2019-07-31 2019年7月31日19:35:17
    [BOM.xlsx, LCD.sch, Memory.sch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]
2019-07-31 2019年7月31日22:38:42
    [BOM.xlsx, EEPROM.sch, KeyPad.sch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]
2019-08-02 2019年8月2日17:20:27
    [BOM.xlsx, KeyPad.sch, MicroController.sch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]
2019-08-02 2019年8月2日22:12:35 nz BOM
    [BOM.xlsx]
2019-08-07 2019年8月7日16:31:33 with new BOM
    [BOM.xlsx]
2019-08-07 2019年8月7日23:49:37 using DC motor rather than stepper motor
    [MicroController.sch, motor driver.sch, ~MicroController.sch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]
2019-08-08 2019年8月9日01:36:38 add readme.md
2019-08-13 2019年8月13日21:48:15 re-orgenize files
    [NanoV3.3.3.sch]
2019-08-13 2019年8月13日21:56:09 school BOM
    [BOM.xlsx]
2019-08-13 2019年8月14日00:46:33
    [~DS1302.sch, ~DS3231.sch, ~IO expander.sch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]
2019-08-13 2019年8月14日00:48:56 new block diagram
    [BOM.xlsx]
2019-08-13 2019年8月14日00:51:23 update readme.md
2019-08-13 2019年8月14日00:56:46 resize the png image
2019-08-14 2019年8月14日23:59:12 1 PSU加电容 2 修改MD部分原理图，暂时放弃加电流监测的想法 3 修改RTC的接线，使用成品shield 4 加reed sw 5 加霍尔传感器 6【最重要的】 重新分配微处理器的引脚
    [EEPROM.sch, KeyPad.sch, LM358N_NOPB.stl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]
2019-08-14 2019年8月15日00:52:02 todo: add diode to MD
    [PSU.sch, motor driver.sch]
2019-08-16 2019年8月16日20:24:21
    [LCD.sch, MicroController.sch, motor driver.sch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]
2019-08-17 2019年8月18日01:03:27 1 修改keyped，加上拉电阻 2 修改保险丝footprint 3 更新部分header名字 4 MD加二极管 5 也许还有更多？？？
    [KeyPad.sch, LCD.sch, MicroController.sch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]
2019-08-21 2019年8月21日17:51:40 change keypad to 4*4
    [KeyPad.sch, LCD.sch, MicroController.sch]
2019-11-12 2019年11月12日14:58:20 first commit，所有设计加了边框
    [EEPROM.sch, KeyPad.sch, LCD.sch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]
2019-11-12 2019年11月13日00:45:42 PCB layout基本完成，只剩下LCD部分
    [EEPROM.sch, LCD.sch, MicroController.sch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]
2019-11-13 PCB完成
    [KeyPad.sch, LCD.sch, MicroController.sch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]
2019-11-14 2019年11月14日14:04:58
2019-11-16 1. add current shunt, 2 track width fixed 3...
    [MicroController.sch, motor driver.sch]
2019-11-21 BOM done
    [BOM.csv, BOM.xlsx]
2019-11-27 2019年11月27日16:37:54 final. add design spark lib to design folder . organize the report folder

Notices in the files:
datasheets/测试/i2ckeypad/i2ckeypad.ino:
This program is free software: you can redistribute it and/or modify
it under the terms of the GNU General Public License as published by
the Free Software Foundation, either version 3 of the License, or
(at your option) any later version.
